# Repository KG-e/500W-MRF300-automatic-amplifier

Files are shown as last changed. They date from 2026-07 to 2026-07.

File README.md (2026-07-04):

# 500W-MRF300-automatic-amplifier

A fully automatic 500 W HF amateur radio amplifier (3.5–28 MHz) using a push-pull MRF300 LDMOS output stage with transmission-line transformers (TLTs). The amplifier automatically measures operating frequency, selects the appropriate low-pass filter, adjusts input drive power, monitors protection systems, and includes an automatic antenna tuner and touchscreen HMI.

**Author:** S56KG (https://www.qrz.com/db/S56KG)
This was a final-year high school project (slovenian "tehnična poklicna matura")

---

## Overview

Commercial automatic HF amplifiers with equivalent specs typically cost **3,000–5,000€**. This project was set out to build a comparable **500W HF amplifier** - with automatic band switching, automatic input leveling (attenuator), and full protection circuitry - for half the price (built for ~1,500€ including six output transistors lost to testing mishaps; a second build would cost roughly **1,300€**).

Unlike most homebrew amplifiers, the goal here was full automation: no manual band switching, no manual tuning sequence - just key up and go.

klub

## Key Features

- **Fully automatic operation** - no manual warm-up/tuning procedure required
- **Automatic input attenuator** with power measurement, stepping through 0.5–6 dB stages to hit an ideal ~4W drive level
- **Push-pull output stage** using 2× MRF300 LDMOS transistors, up to ~530W PEP, depending on freq.
- **Automatic low-pass filter selection** based on measured carrier frequency (LPF harmonics are ≤ −65 dBc)
- **Dual-MCU architecture** (2× ATmega2560) communicating over UART, with a custom protocol (type-checked, range-checked, heartbeat-monitored)
- **Nextion touchscreen HMI** showing forward/reflected power, SWR, current, temperature, state, band, gain, and losses in real time
- **Full protection**: overcurrent shutdown (soft-latched via SET-RESET logic), SWR protection, thermal protection, bias monitoring
- **Built-in antenna tuner board** (7x7 L-network, based on the N7DDC ATU-100 topology) - hardware complete, control algorithm in testing
- Extra feature connectors for future interfacing (not yet made PC digital control using a PiPico server) 
- Backup analog voltage/current meter on the front panel

## Design Goals

- At least 450W output
- Fully automatic operation without manual tuning
- Comprehensive protection for the MRF300 output devices 
- Support contest-style rapid TX/RX switching
- Maintain harmonic suppression below −65 dBc
- Operate from 3.5–28 MHz with automatic band detection
- Provide a commercial-style touchscreen HMI for all key operational values
- Build using only readily available components on DigiKey

## How It Works

block sheme

**Transmit state machine:** `INIT → WAIT → FIRST START → INPUT SETUP → LOW POWER TX → TX SWITCH → HIGH POWER TX → READY`. The "ready" state remembers the last transmission and skips most of the setup sequence on the next key-up for faster switching, useful for competition use.

statemachine

## Power/SWR Measurement

Power and SWR are measured using a **tandem match coupler**, rather than a simple directional coupler, since directional couplers perform poorly at low freq. HF. Two transformers (current and voltage) are summed/negated to separate forward and reflected power. Each direction feeds an **AD8310** logarithmic RF power detector (for accuracy across a wide dynamic range, from milliwatts to hundreds of watts), digitized by two 16-bit **ADS1115** ADCs over I2C.

## Boards 
| 1 | Attenuator board | Auto input attenuator (relay-switched, 0.5–6 dB stages, 8 stage), input power/SWR meter, built-in 50ohm dummy load 

| 2 | MCU board | Carrier board for ATmega2560 + ATmega16U2 (Arduino Mega-derived); one per controller 

| 3 | Amplifier board | Push-pull 2× MRF300 output stage, TLT output transformers, high-side current sensing, hardware overcurrent latch 

| 4 | Filter board | Output power/SWR metering + auto-selected low-pass filters (designed in AADE Filter Design + LTspice) 

| 5 | Tuner board | 7x7 L-network automatic antenna tuner (hardware complete, not yet enabled) 

| 6 | Motherboard | MCU carrier, per-board regulated supplies, fan control (6× PWM), 2× ADS1115 ADC, buzzer, overcurrent sensing 

| 7 | Input board | RX/TX switching (opto-isolated relay drive), 50V enable, frequency counter 

All boards are 4-layer FR4 (except the tuner board, 2-layer), designed with trace impedance calculated per JLCPCB dielectric specs.

## Firmware

- Two **ATmega2560** microcontrollers, split because driving the Nextion HMI alone slows a single loop to >30ms. This separates time-critical amplifier control from the touchscreen interface to guarantee deterministic protection response.
  - **Primary MCU**: runs the amplifier state machine, controls the amp stage, PSU, RF switching, attenuator, and filters; measures frequency and enforces fast protection (SWR, current, voltage) every loop.
  - **Secondary MCU**: reads temperature/voltage sensors, drives cooling fans, and manages the Nextion HMI.
- Custom UART protocol between the two MCUs with type checking, range validation, and a heartbeat/ID exchange so a reset on either side is detected.
- Faults are split into **soft** (recoverable, resettable from the HMI) and **hard** (critical) — the system is designed so no single fault destroys hardware (in theory, needs more testing to be sure).
- Developed in PlatformIO / VS Code (migrated from Arduino IDE to allow project specific library configuration, needed to change the UART RX buffer without touching global libraries).
- Combined firmware exceeds 3,000 lines across both MCUs.

## HMI

A **Nextion NX4832F035** touchscreen HMI displays input/output power and SWR (with slider gauges), current, temperature, operating state, faults, detected band, gain, and loss — with on-screen soft-fault reset and SSB mode toggle buttons.

## Power Supply

- Toroidal transformer 1200VA and 17V iron core feeding regulated **50V** and **18V** rails respectively, plus soft-start circuitry (needed after an initial testing inrush blew ten smd fuses at once).
- 50V rail: 5x TIP35C NPN transistors (more than strictly needed by current, added for thermal headroom due to insulators).
- 18V rail: 5x LM7818 in a balanced parallel configuration.
- Each PCB has its own local LM78xx/LT1117 regulation on the motherboard to isolate RF noise between stages — important since the amplifier operates on the same frequencies the MCUs use internally.
- Tested at 800W (80% load) for several hours for thermal verification.

## Specifications

| Parameter | Value |
|---|---|
| Output power | 450–500 W (typ.) |
| Accepted drive power | 7–110 W |
| Bands | 3.5, 7, 10, 14, 18, 21, 27 (CB), 28 MHz |
| Gain | > 17 dB (typ.) |
| DC-RF efficiency | ~50% |
| Modes | FM, SSB |
| Harmonics | ≤ −65 dBc |
| Max. antenna SWR | 4:1 |
| Weight | 21.3 kg |
| Dimensions (DxWxH) | 48 × 44 × 20 cm |

## Known Issues

- Occasional spurious fault triggering under unusual operating conditions
- Secondary MCU can fail to start correctly, due to a Nextion library issue that stalls its main loop
- AM modulation is not supported (breaks the frequency counter)
- Reduced output power on the 28 MHz band, due to a suboptimal low-pass filter design in the current revision
- Higher drive power required on 21 MHz and 28 MHz (12W, compared to 7W on 3.5MHz) due to RF detector attenuation characteristics
- The bad 28 MHz LPF has elevated output SWR, degrading output power/SWR readings on that band
- Automatic antenna tuner's hardware is complete but not yet fully tested as the matching algorithm is a difficult mechanism, still under development 
- Lower than desired efficiency of the amp stage, currently about 50%, which pushes power dissipation to the limit
 
This project is shared as inspiration for design ideas, for other homebrew amp builders. I do not recommend attempting to recreate my exact design as there are many subtle details one must account for when building it that you may not know or find unless you are very thorough and understanding of the design.

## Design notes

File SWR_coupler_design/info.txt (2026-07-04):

The design of the coupler was copied from https://vk6nx.net/SWR-PWRmeter_v1.0-en.html#00
Only small changes were made from this example.

The coupler is accurate to +-0.2W when Pin<10W, +-1W when Pin>100W. Directivity is around 20dB with the internal shielding in the toroid (look at input bridge picture) 
and around 15dB without (look at output bridge picture). Directivity worsens with higher input power. This is due to the stray capacitance between the fwd and rev ports.

This design can handle around 1kW of power. vk6nex lists 2kW, but calculating directivity drop makes it unusable as a actual SWR meter at those powers.

Added file is a example cal table from the amplifier. To get cal values i actualy reccomend putting the data into a LLM such as Claude, to speed up brute 
calibration factor calculations... Cal values are stored in the custom ADC library.

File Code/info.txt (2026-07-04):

If you wish correctly open these files, you must download Visual Studio Code and the platformio extension for the files to combine correctly.

Libraries ADC and UART are custom made for this project, it is not reccomended to use them out of this scope unless you realy know what you are doing.

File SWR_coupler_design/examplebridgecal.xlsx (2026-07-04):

OUTPUT BRIDGE | TrueFwdW | 29MEG | FWD | REW | TrueFwdW | 24MEG | FWD | REW | TrueFwdW | 14MEG | FWD | REW | TrueFwdW | 7MEG | FWD | REW | TrueFwdW | 3.5MEG | FWD | REW
 | 9 |  | 2037 | 1789 | 9.5 |  | 2043 | 1772 | 9.5 |  | 2043 | 1671 | 10 |  | 2045 | 1542 | 10 |  | 2049 | 1425
 | 19 |  | 2110 | 1859 | 19 |  | 2117 | 1884 | 20 |  | 2121 | 1745 | 20 |  | 2122 | 1610 | 20 |  | 2127 | 1500
 | 38 |  | 2186 | 1929 | 40 |  | 2193 | 1916 | 40 |  | 2196 | 1820 | 40 |  | 2196 | 1677 | 40 |  | 2201 | 1569
 | 57 |  | 2227 | 1968 | 60 |  | 2236 | 1955 | 60 |  | 2238 | 1835 | 60 |  | 2239 | 1721 | 60 |  | 2245 | 1609
 | 75 |  | 2257 | 1997 | 80 |  | 2265 | 1985 | 81 |  | 2268 | 1868 | 80 |  | 2270 | 1754 | 81 |  | 2276 | 1639
 | 76 |  | 2260 | 2000 | 104 |  | 2291 | 2008 | 104 |  | 2290 | 1915 | 105 |  | 2295 | 1781 | 105 |  | 2302 | 1664
INPUT BRIDGE | TrueFwdW | 29MEG | FWD | REW | TrueFwdW | 24MEG | FWD | REW | TrueFwdW | 14MEG | FWD | REW | TrueFwdW | 7MEG | FWD | REW | TrueFwdW | 3.5MEG | FWD | REW
 | 10 |  | 2063 | 1700 | 10 |  | 2062 | 1652 | 10 |  | 2061 | 1496 | 10 |  | 2062 | 1371 | 10 |  | 2070 | 1351
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

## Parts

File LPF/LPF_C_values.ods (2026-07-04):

values for | F1 – 3.5 | F2 – 7 | F3 – 14 | F4 – 21 | F5 – 28 | C-pcb removed(17pF) | F1 – 3.5 | F2 – 7 | F3 – 14 | F4 – 21 | F5 – 28
C1 | 1100 | 545 | 280 | 165 | 125 | ---→ | 1083 | 528 | 263 | 148 | 108
C2 | 25 | 30 | 10 | 15 | 10 |  | 8 | 13 | -7 | -2 | -7
C3 | 1700 | 845 | 435 | 265 | 210 |  | 1683 | 828 | 418 | 248 | 193
C4 | 60 | 75 | 30 | 35 | 15 |  | 43 | 58 | 13 | 18 | -2
C5 | 900 | 505 | 260 | 145 | 120 |  | 883 | 488 | 243 | 128 | 103
L1 | 2.5 | 1.35 | 0.68 | 0.45 | 0.33
L2 | 2.55 | 1.25 | 0.63 | 0.38 | 0.32
 | F1 – 3.5 | <-stacked C | F2 – 7 | ←stacked C | F3 – 14 | ←stacked C | F4 – 21 | <-stacked C | F5 – 28 | ←stacked C |  | stacked C is due to the series connection of
 | 1083 | 2166 | 528 | 1056 | 263 | 526 | 148 | 296 | 108 | 216 |  | two capacitors for higher power and dissipation.
 | 8 | 16 | 13 | 26 | -7 | -14 | -2 | -4 | -7 | -14 |  | Use only large size capacitors, 1kV of C0G. Tune all LPF’s manually with a VNA connected.
 | 1683 | 3366 | 828 | 1656 | 418 | 836 | 248 | 496 | 193 | 386 |  | I advise the use of variable capacitors across all capacitor locations
 | 43 | 86 | 58 | 116 | 13 | 26 | 18 | 36 | -2 | -4 |  | to quickly estimate values for a correct response.
 | 883 | 1766 | 488 | 976 | 243 | 486 | 128 | 256 | 103 | 206 |  | Final check is via radio, 100W, checking input and output SWR
 |  |  |  |  |  |  |  |  |  |  |  | these are aproximate values. In my testing true values ranged in +-10%…
 |  | 2166 / 16 3366 / 86 1766 / |  | 1056 / 26 1656 / 116 976 / |  | 526 / -14 836 26 486 / |  | 296 -4 496 / 36 256 / |  | 216 / -14 386 -4 206 /
aprox |  | Capacitors to buy
2000 x2 + 100 x2 + 30 x4 |  | 2000 x4
3300 x2 + 30 x4 |  | 100 x30
1600 x4 + 100 x2 + 30 x4 |  | 30x30
900 x4 + 80 x2 + 30x4 |  | 80x10
480 x4 + 10 x4 |  | 10x30
800 x2 + 20 x8 |  | 3300 x4
200 x 12 + 20 x2 + 50 x2 |  | 20x 30
100 x4 + 50 x2 + 30 x2 |  | 50x 20
5p, 10p |  | 5x 30
 |  | 480 x14
 |  | 900 x6
 |  | 1600 x6

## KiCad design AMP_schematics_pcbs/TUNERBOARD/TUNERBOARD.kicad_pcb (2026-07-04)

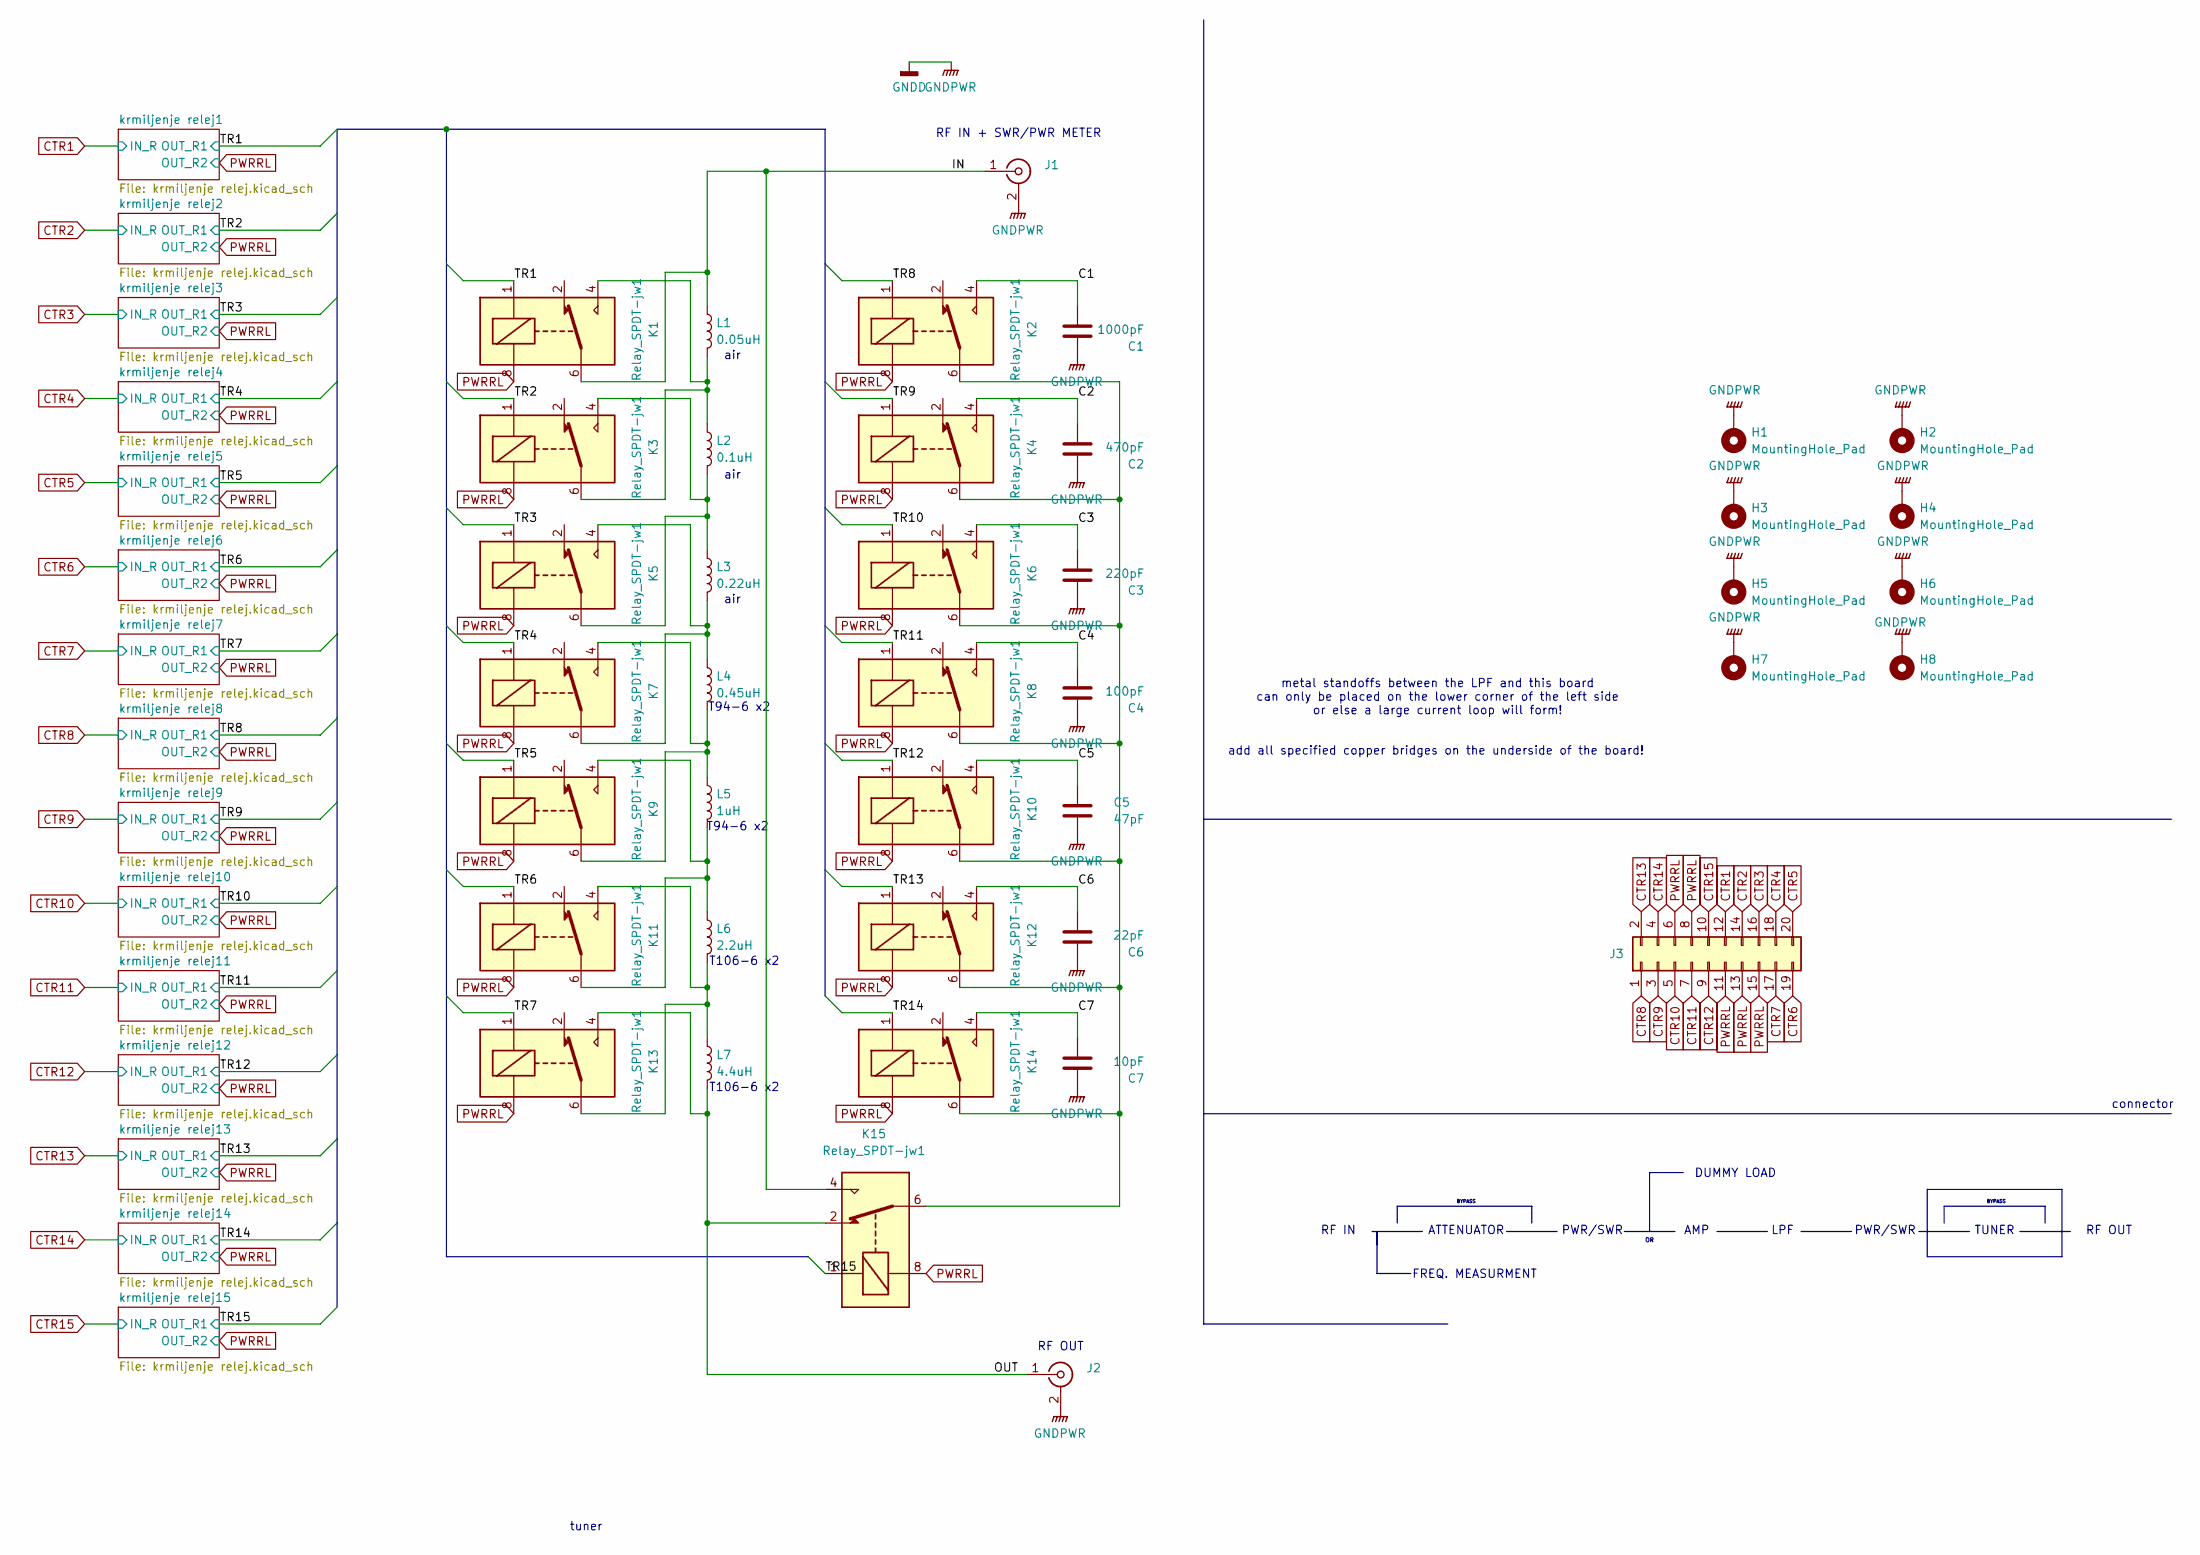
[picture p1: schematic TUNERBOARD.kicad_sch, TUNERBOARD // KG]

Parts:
C1: 1000pF; C_1210_3225Metric
C2: 470pF; C_1210_3225Metric
C3: 220pF; C_1210_3225Metric
C4: 100pF; C_1210_3225Metric
C5: 47pF; C_1210_3225Metric
C6: 22pF; C_1210_3225Metric
C7: 10pF; C_1210_3225Metric
H1, H2, H3, H4, H5, H6, H7, H8: MountingHole_Pad; MountingHole_3.2mm_M3_Pad_TopBottom
J1, J2: Conn_Coaxial; SMA_Amphenol_132134_Vertical
J3: Conn_02x10_Odd_Even; PinHeader_2x10_P2.54mm_Vertical
K1, K2, K3, K4, K5, K6, K7, K8, K9, K10, K11, K12, K13, K14, K15: Relay_SPDT-jw1; Relay_premaknjen
L1: 0.05uH; zracnatuljava
L2: 0.1uH; zracnatuljava
L3: 0.22uH; zracnatuljava
L4: 0.45uH; T94-postrani
L5: 1uH; T94-postrani
L6: 2.2uH; T106-lezec
L7: 4.4uH; T106-lezec

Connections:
/C1: C1.2, K2.4
/C2: C2.2, K4.4
/C3: C3.2, K6.4
/C4: C4.2, K8.4
/C5: C5.2, K10.4
/C6: C6.2, K12.4
/C7: C7.2, K14.4
/IN: J1.1 (In), K1.6, K15.4, L1.1
/OUT: J2.1 (In), K13.4, K15.2, L7.2
/TR1: K1.1; also elsewhere on the board
/TR2: K3.1; also elsewhere on the board
/TR3: K5.1; also elsewhere on the board
/TR4: K7.1; also elsewhere on the board
/TR5: K9.1; also elsewhere on the board
/TR6: K11.1; also elsewhere on the board
/TR7: K13.1; also elsewhere on the board
/TR8: K2.1; also elsewhere on the board
/TR9: K4.1; also elsewhere on the board
/TR10: K6.1; also elsewhere on the board
/TR11: K8.1; also elsewhere on the board
/TR12: K10.1; also elsewhere on the board
/TR13: K12.1; also elsewhere on the board
/TR14: K14.1; also elsewhere on the board
/TR15: K15.1; also elsewhere on the board
CTR1: J3.12; also elsewhere on the board
CTR2: J3.14; also elsewhere on the board
CTR3: J3.16; also elsewhere on the board
CTR4: J3.18; also elsewhere on the board
CTR5: J3.20; also elsewhere on the board
CTR6: J3.19; also elsewhere on the board
CTR7: J3.17; also elsewhere on the board
CTR8: J3.1; also elsewhere on the board
CTR9: J3.3; also elsewhere on the board
CTR10: J3.5; also elsewhere on the board
CTR11: J3.7; also elsewhere on the board
CTR12: J3.9; also elsewhere on the board
CTR13: J3.2; also elsewhere on the board
CTR14: J3.4; also elsewhere on the board
CTR15: J3.10; also elsewhere on the board
GNDD: C1.1, C2.1, C3.1, C4.1, C5.1, C6.1, C7.1, H1.1, H2.1, H3.1, H4.1, H5.1, H6.1, H7.1, H8.1, J1.2 (Ext), J2.2 (Ext); also elsewhere on the board
unnamed: K1.4, K3.6, L1.2, L2.1
unnamed: K3.4, K5.6, L2.2, L3.1
unnamed: K5.4, K7.6, L3.2, L4.1
unnamed: K7.4, K9.6, L4.2, L5.1
unnamed: K2.6, K4.6, K6.6, K8.6, K10.6, K12.6, K14.6, K15.6
unnamed: K11.4, K13.6, L6.2, L7.1
unnamed: K9.4, K11.6, L5.2, L6.1
PWRRL: J3.6, J3.8, J3.11, J3.13, J3.15, K1.8, K2.8, K3.8, K4.8, K5.8, K6.8, K7.8, K8.8, K9.8, K10.8, K11.8, K12.8, K13.8, K14.8, K15.8; also elsewhere on the board

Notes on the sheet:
T106-6 x2
ATTENUATOR
add all specified copper bridges on the underside of the board!
DUMMY LOAD
RF OUT
FREQ. MEASURMENT
AMP
LPF
air
PWR/SWR
RF OUT
RF IN + SWR/PWR METER
BYPASS
T94-6 x2
TUNER
RF IN
tuner
metal standoffs between the LPF and this board can only be placed on the lower corner of the left side or else a large current loop will form!
connector

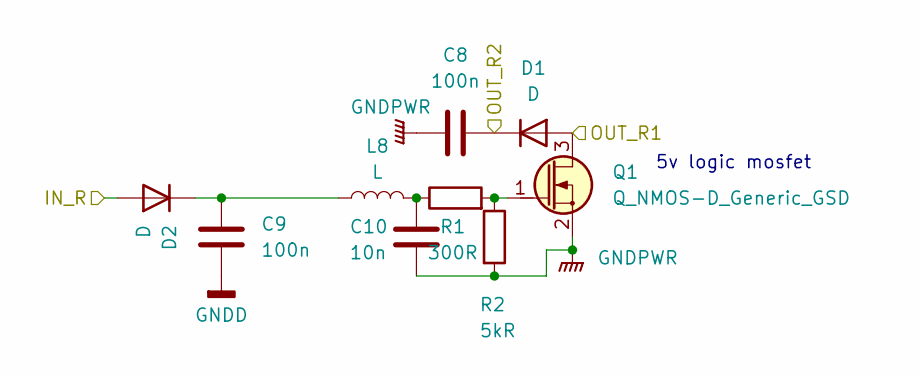
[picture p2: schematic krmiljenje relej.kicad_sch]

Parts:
C8, C9: 100n; C_1206_3216Metric_Pad1.33x1.80mm_HandSolder
C10: 10n; C_1206_3216Metric_Pad1.33x1.80mm_HandSolder
D1, D2: D; D_1206_3216Metric_Pad1.42x1.75mm_HandSolder
L8: L; Ferrite_1206_3216Metric_Pad1.42x1.75mm_BigPads
Q1: Q_NMOS-D_Generic_GSD; TSOT-23_HandSoldering
R1: 300R; R_1206_3216Metric_Pad1.30x1.75mm_HandSolder
R2: 5kR; R_1206_3216Metric_Pad1.30x1.75mm_HandSolder

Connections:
/TR1: D1.2 (A), Q1.3 (D); also elsewhere on the board
CTR1: D2.2 (A); also elsewhere on the board
GNDD: C8.2, C9.2, C10.2, Q1.2 (S), R2.2; also elsewhere on the board
unnamed: C10.1, L8.2, R1.1
unnamed: C9.1, D2.1 (K), L8.1
unnamed: Q1.1 (G), R1.2, R2.1
PWRRL: C8.1, D1.1 (K); also elsewhere on the board

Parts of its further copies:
C11, C12, C14, C15, C17, C18, C20, C21, C23, C24, C26, C27, C29, C30, C32, C33, C35, C36, C38, C39, C41, C42, C44, C45, C47, C48, C50, C51: 100n; C_1206_3216Metric_Pad1.33x1.80mm_HandSolder
C13, C16, C19, C22, C25, C28, C31, C34, C37, C40, C43, C46, C49, C52: 10n; C_1206_3216Metric_Pad1.33x1.80mm_HandSolder
D3, D4, D5, D6, D7, D8, D9, D10, D11, D12, D13, D14, D15, D16, D17, D18, D19, D20, D21, D22, D23, D24, D25, D26, D27, D28, D29, D30: D; D_1206_3216Metric_Pad1.42x1.75mm_HandSolder
L9, L10, L11, L12, L13, L14, L15, L16, L17, L18, L19, L20, L21, L22: L; Ferrite_1206_3216Metric_Pad1.42x1.75mm_BigPads
Q2, Q3, Q4, Q5, Q6, Q7, Q8, Q9, Q10, Q11, Q12, Q13, Q14, Q15: Q_NMOS-D_Generic_GSD; TSOT-23_HandSoldering
R3, R5, R7, R9, R11, R13, R15, R17, R19, R21, R23, R25, R27, R29: 300R; R_1206_3216Metric_Pad1.30x1.75mm_HandSolder
R4, R6, R8, R10, R12, R14, R16, R18, R20, R22, R24, R26, R28, R30: 5kR; R_1206_3216Metric_Pad1.30x1.75mm_HandSolder

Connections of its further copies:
/TR2: D3.2 (A), Q2.3 (D); also elsewhere on the board
/TR3: D5.2 (A), Q3.3 (D); also elsewhere on the board
/TR4: D7.2 (A), Q4.3 (D); also elsewhere on the board
/TR5: D9.2 (A), Q5.3 (D); also elsewhere on the board
/TR6: D11.2 (A), Q6.3 (D); also elsewhere on the board
/TR7: D13.2 (A), Q7.3 (D); also elsewhere on the board
/TR8: D15.2 (A), Q8.3 (D); also elsewhere on the board
/TR9: D17.2 (A), Q9.3 (D); also elsewhere on the board
/TR10: D19.2 (A), Q10.3 (D); also elsewhere on the board
/TR11: D21.2 (A), Q11.3 (D); also elsewhere on the board
/TR12: D23.2 (A), Q12.3 (D); also elsewhere on the board
/TR13: D25.2 (A), Q13.3 (D); also elsewhere on the board
/TR14: D27.2 (A), Q14.3 (D); also elsewhere on the board
/TR15: D29.2 (A), Q15.3 (D); also elsewhere on the board
CTR2: D4.2 (A); also elsewhere on the board
CTR3: D6.2 (A); also elsewhere on the board
CTR4: D8.2 (A); also elsewhere on the board
CTR5: D10.2 (A); also elsewhere on the board
CTR6: D12.2 (A); also elsewhere on the board
CTR7: D14.2 (A); also elsewhere on the board
CTR8: D16.2 (A); also elsewhere on the board
CTR9: D18.2 (A); also elsewhere on the board
CTR10: D20.2 (A); also elsewhere on the board
CTR11: D22.2 (A); also elsewhere on the board
CTR12: D24.2 (A); also elsewhere on the board
CTR13: D26.2 (A); also elsewhere on the board
CTR14: D28.2 (A); also elsewhere on the board
CTR15: D30.2 (A); also elsewhere on the board
GNDD: C11.2, C12.2, C13.2, C14.2, C15.2, C16.2, C17.2, C18.2, C19.2, C20.2, C21.2, C22.2, C23.2, C24.2, C25.2, C26.2, C27.2, C28.2, C29.2, C30.2, C31.2, C32.2, C33.2, C34.2, C35.2, C36.2, C37.2, C38.2, C39.2, C40.2, C41.2, C42.2, C43.2, C44.2, C45.2, C46.2, C47.2, C48.2, C49.2, C50.2, C51.2, C52.2, Q2.2 (S), Q3.2 (S), Q4.2 (S), Q5.2 (S), Q6.2 (S), Q7.2 (S), Q8.2 (S), Q9.2 (S), Q10.2 (S), Q11.2 (S), Q12.2 (S), Q13.2 (S), Q14.2 (S), Q15.2 (S), R4.2, R6.2, R8.2, R10.2, R12.2, R14.2, R16.2, R18.2, R20.2, R22.2, R24.2, R26.2, R28.2, R30.2; also elsewhere on the board
unnamed: C13.1, L9.2, R3.1
unnamed: C16.1, L10.2, R5.1
unnamed: C19.1, L11.2, R7.1
unnamed: C22.1, L12.2, R9.1
unnamed: C25.1, L13.2, R11.1
unnamed: C28.1, L14.2, R13.1
unnamed: C31.1, L15.2, R15.1
unnamed: C34.1, L16.2, R17.1
unnamed: C37.1, L17.2, R19.1
unnamed: C40.1, L18.2, R21.1
unnamed: C43.1, L19.2, R23.1
unnamed: C46.1, L20.2, R25.1
unnamed: C49.1, L21.2, R27.1
unnamed: C52.1, L22.2, R29.1
unnamed: C12.1, D4.1 (K), L9.1
unnamed: C15.1, D6.1 (K), L10.1
unnamed: C18.1, D8.1 (K), L11.1
unnamed: C21.1, D10.1 (K), L12.1
unnamed: C24.1, D12.1 (K), L13.1
unnamed: C27.1, D14.1 (K), L14.1
unnamed: C30.1, D16.1 (K), L15.1
unnamed: C33.1, D18.1 (K), L16.1
unnamed: C36.1, D20.1 (K), L17.1
unnamed: C39.1, D22.1 (K), L18.1
unnamed: C42.1, D24.1 (K), L19.1
unnamed: C45.1, D26.1 (K), L20.1
unnamed: C48.1, D28.1 (K), L21.1
unnamed: C51.1, D30.1 (K), L22.1
unnamed: Q2.1 (G), R3.2, R4.1
unnamed: Q3.1 (G), R5.2, R6.1
unnamed: Q4.1 (G), R7.2, R8.1
unnamed: Q5.1 (G), R9.2, R10.1
unnamed: Q6.1 (G), R11.2, R12.1
unnamed: Q7.1 (G), R13.2, R14.1
unnamed: Q8.1 (G), R15.2, R16.1
unnamed: Q9.1 (G), R17.2, R18.1
unnamed: Q10.1 (G), R19.2, R20.1
unnamed: Q11.1 (G), R21.2, R22.1
unnamed: Q12.1 (G), R23.2, R24.1
unnamed: Q13.1 (G), R25.2, R26.1
unnamed: Q14.1 (G), R27.2, R28.1
unnamed: Q15.1 (G), R29.2, R30.1
PWRRL: C11.1, C14.1, C17.1, C20.1, C23.1, C26.1, C29.1, C32.1, C35.1, C38.1, C41.1, C44.1, C47.1, C50.1, D3.1 (K), D5.1 (K), D7.1 (K), D9.1 (K), D11.1 (K), D13.1 (K), D15.1 (K), D17.1 (K), D19.1 (K), D21.1 (K), D23.1 (K), D25.1 (K), D27.1 (K), D29.1 (K); also elsewhere on the board

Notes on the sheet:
5v logic mosfet

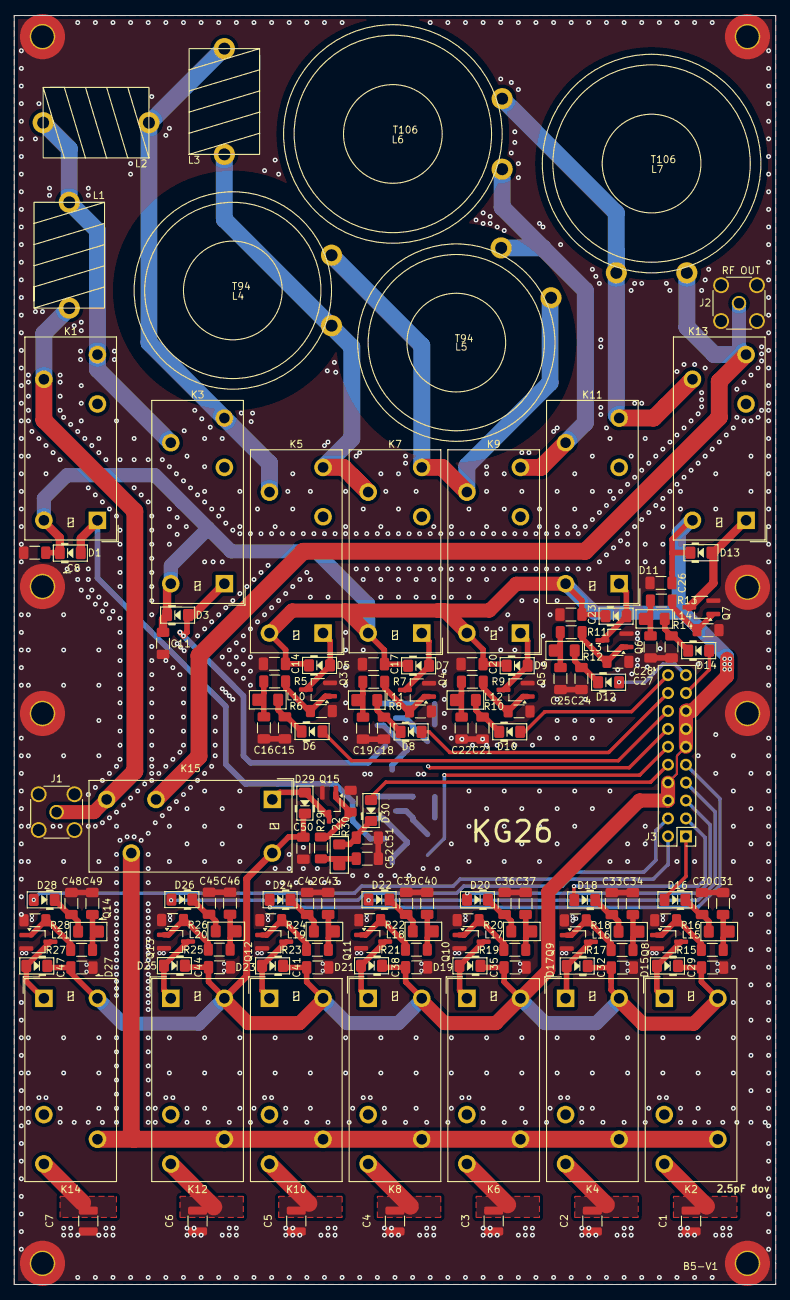
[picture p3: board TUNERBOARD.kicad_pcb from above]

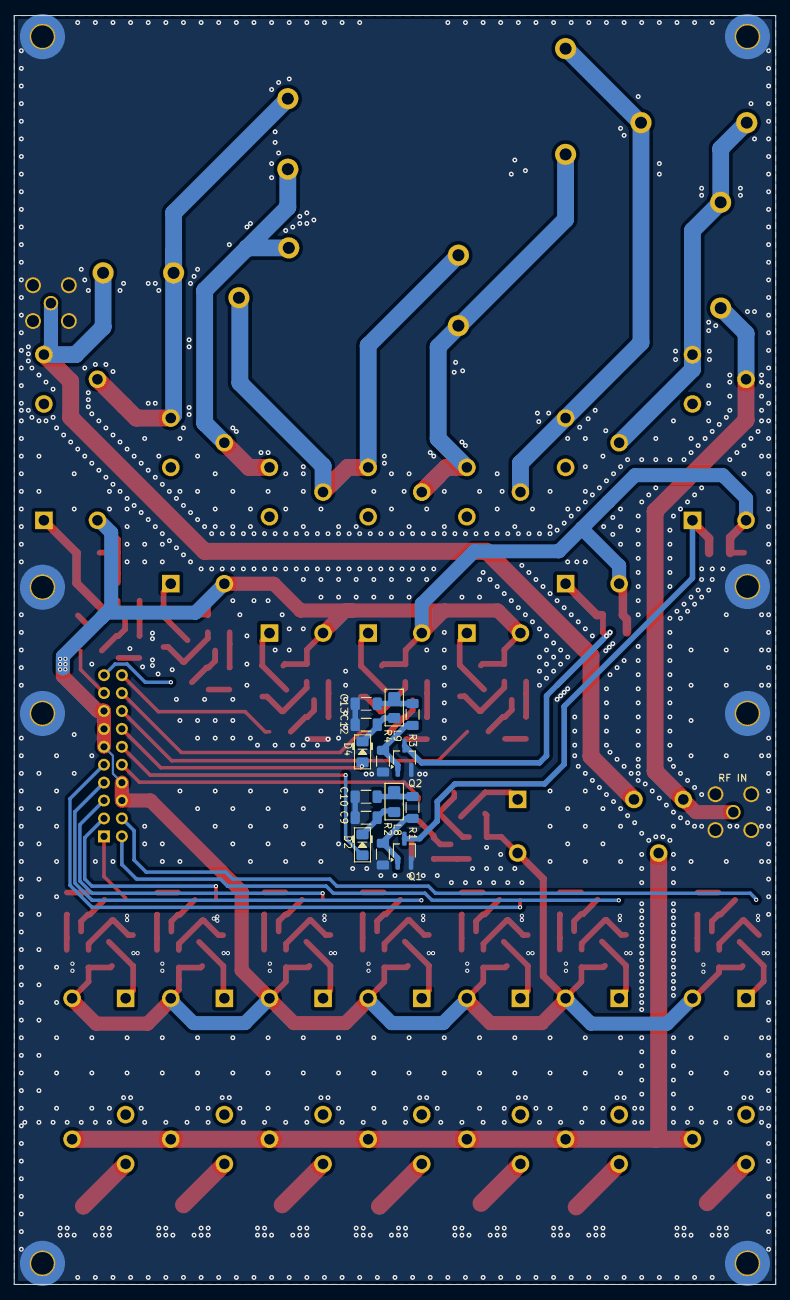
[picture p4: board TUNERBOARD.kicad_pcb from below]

Board: 2 copper layers, 108.0 x 180.0 mm, 175 parts (14 on the bottom side), 93 nets.

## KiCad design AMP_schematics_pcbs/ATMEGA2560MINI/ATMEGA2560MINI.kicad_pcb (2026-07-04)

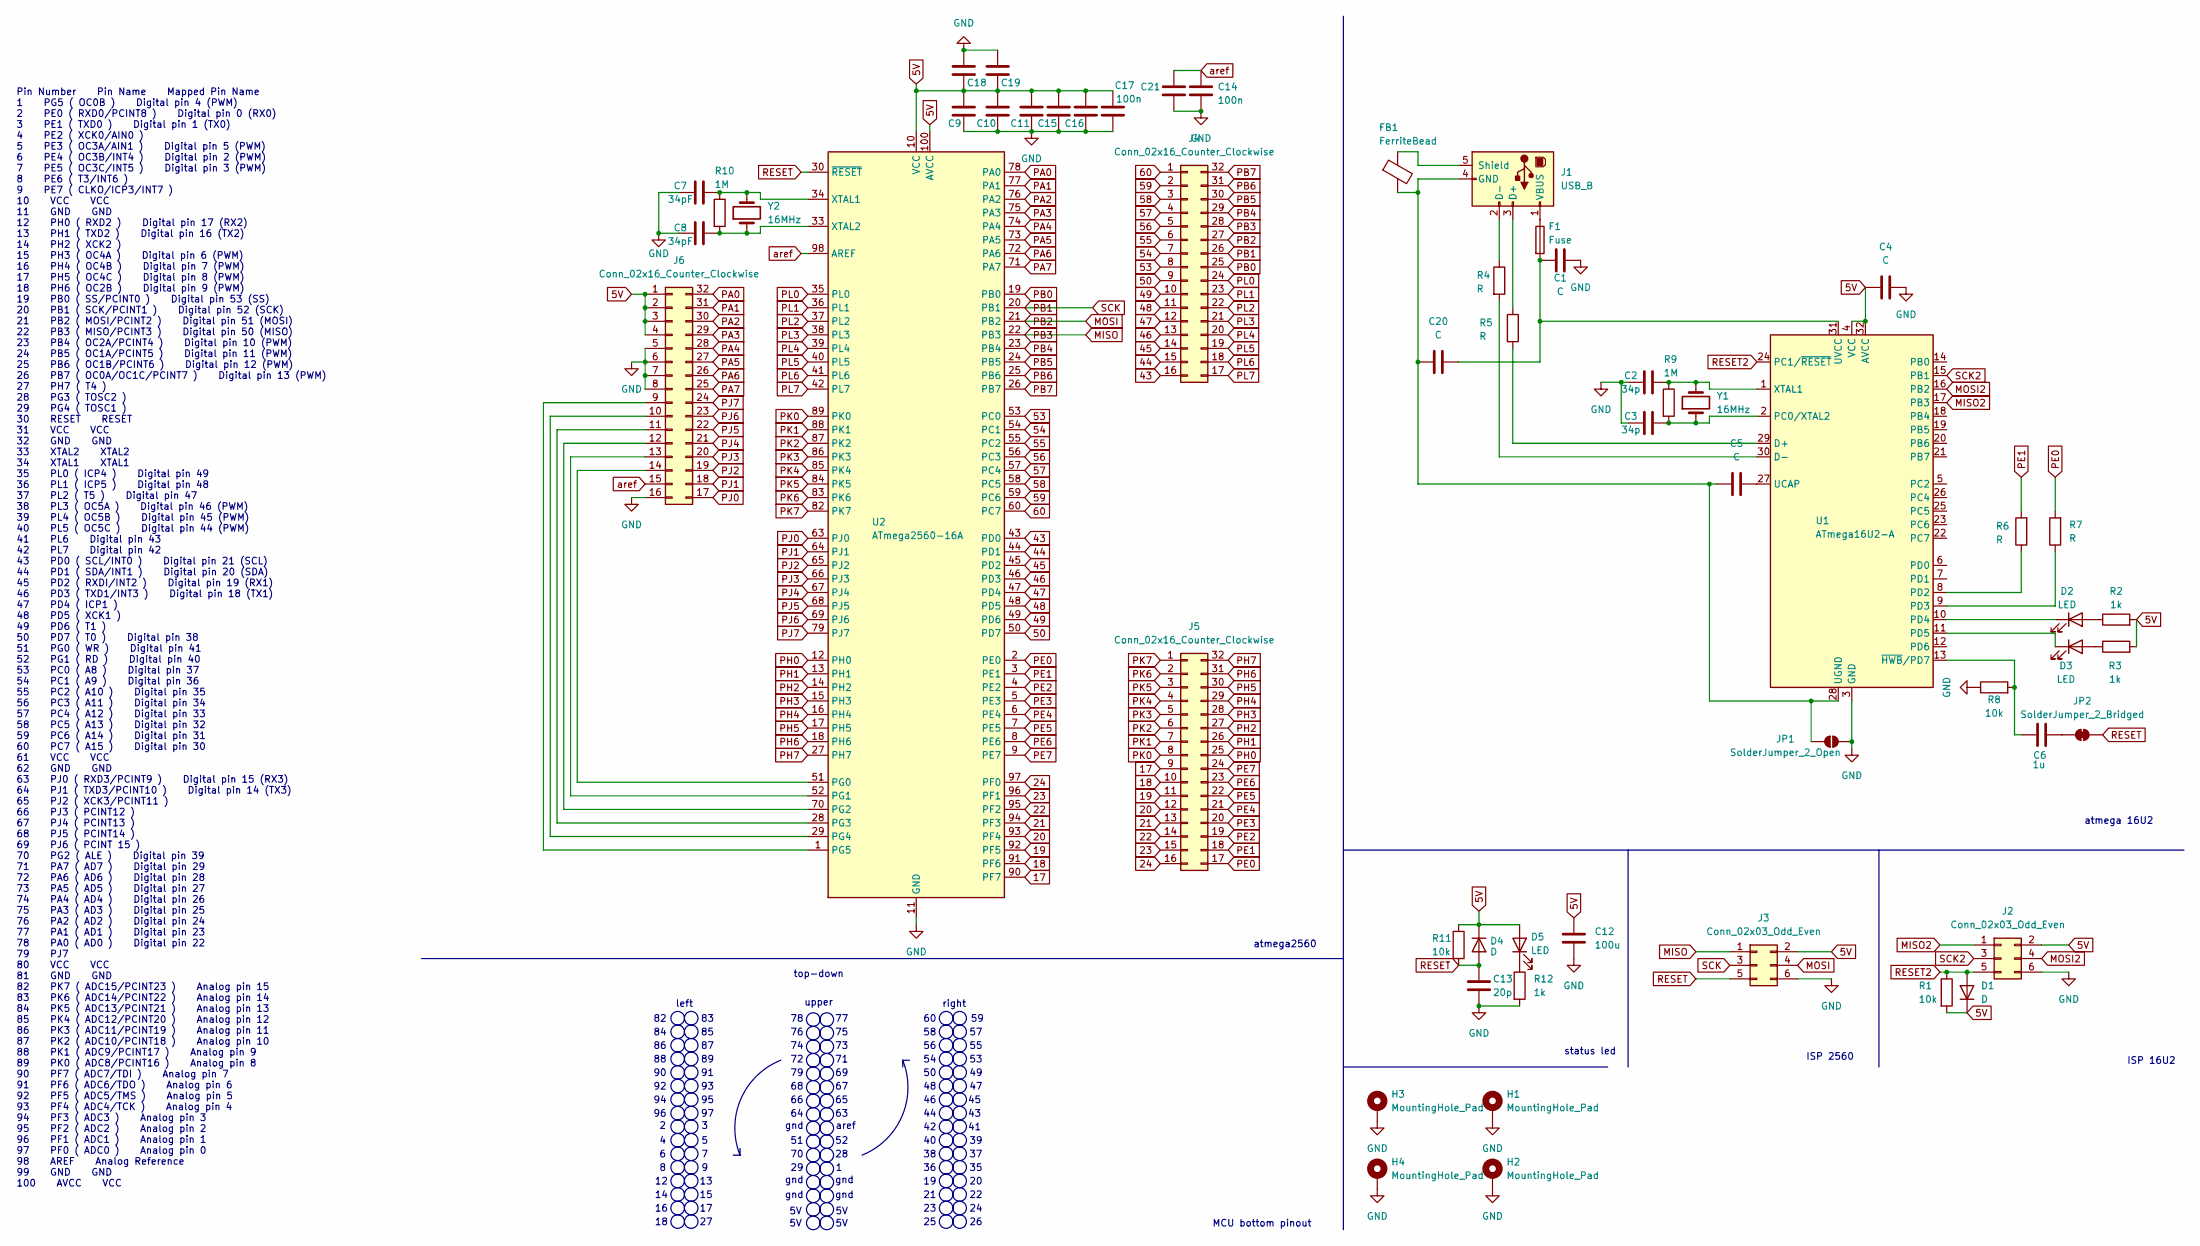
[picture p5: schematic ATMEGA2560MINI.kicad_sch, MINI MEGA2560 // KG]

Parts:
C1, C4, C5, C9, C10, C11, C15, C16, C18, C19, C20, C21: C; C_1206_3216Metric_Pad1.33x1.80mm_HandSolder
C2, C3: 34p; C_1206_3216Metric_Pad1.33x1.80mm_HandSolder
C6: 1u; C_1206_3216Metric_Pad1.33x1.80mm_HandSolder
C7, C8: 34pF; C_1206_3216Metric_Pad1.33x1.80mm_HandSolder
C12: 100u; CP_Elec_8x10
C13: 20p; C_1206_3216Metric_Pad1.33x1.80mm_HandSolder
C14, C17: 100n; C_1206_3216Metric_Pad1.33x1.80mm_HandSolder
D1, D4: D; D_1206_3216Metric_Pad1.42x1.75mm_HandSolder
D2, D3, D5: LED; LED_0805_2012Metric_Pad1.15x1.40mm_HandSolder
F1: Fuse; Fuse_1206_3216Metric_Pad1.42x1.75mm_HandSolder
FB1: FerriteBead; L_1806_4516Metric_Pad1.45x1.90mm_HandSolder
H1, H2, H3, H4: MountingHole_Pad; MountingHole_3.2mm_M3_ISO14580_Pad_TopBottom
J1: USB_B; USB_B_TE_5787834_Vertical
J2, J3: Conn_02x03_Odd_Even; PinSocket_2x03_P2.54mm_Vertical
J4, J5, J6: Conn_02x16_Counter_Clockwise; PinHeader_2x16_P2.54mm_Vertical
JP1: SolderJumper_2_Open; SolderJumper-2_P1.3mm_Open_RoundedPad1.0x1.5mm
JP2: SolderJumper_2_Bridged; SolderJumper-2_P1.3mm_Bridged2Bar_RoundedPad1.0x1.5mm
R1, R8, R11: 10k; R_1206_3216Metric_Pad1.30x1.75mm_HandSolder
R2, R3, R12: 1k; R_1206_3216Metric_Pad1.30x1.75mm_HandSolder
R4, R5, R6, R7: R; R_1206_3216Metric_Pad1.30x1.75mm_HandSolder
R9, R10: 1M; R_1206_3216Metric_Pad1.30x1.75mm_HandSolder
U1: ATmega16U2-A; TQFP-32_7x7mm_P0.8mm
U2: ATmega2560-16A; TQFP-100_14x14mm_P0.5mm
Y1, Y2: 16MHz; Crystal_HC49-U_Vertical

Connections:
5V: C4.1, C9.2, C10.2, C11.2, C12.1, C15.2, C16.2, C17.2, C18.2, C19.2, D1.1 (K), D4.1 (K), D5.2 (A), J2.2, J3.2, J6.1, J6.2, J6.3, J6.4, R1.2, R2.2, R3.2, R11.1, U1.4 (VCC), U1.32 (AVCC), U2.10 (VCC), U2.31 (VCC), U2.61 (VCC), U2.80 (VCC), U2.100 (AVCC)
17: J5.9, U2.90 (PF7)
18: J5.10, U2.91 (PF6)
19: J5.11, U2.92 (PF5)
20: J5.12, U2.93 (PF4)
21: J5.13, U2.94 (PF3)
22: J5.14, U2.95 (PF2)
23: J5.15, U2.96 (PF1)
24: J5.16, U2.97 (PF0)
43: J4.16, U2.43 (PD0)
44: J4.15, U2.44 (PD1)
45: J4.14, U2.45 (PD2)
46: J4.13, U2.46 (PD3)
47: J4.12, U2.47 (PD4)
48: J4.11, U2.48 (PD5)
49: J4.10, U2.49 (PD6)
50: J4.9, U2.50 (PD7)
53: J4.8, U2.53 (PC0)
54: J4.7, U2.54 (PC1)
55: J4.6, U2.55 (PC2)
56: J4.5, U2.56 (PC3)
57: J4.4, U2.57 (PC4)
58: J4.3, U2.58 (PC5)
59: J4.2, U2.59 (PC6)
60: J4.1, U2.60 (PC7)
GND: C1.2, C2.1, C3.1, C4.2, C7.1, C8.1, C9.1, C10.1, C11.1, C12.2, C13.2, C14.1, C15.1, C16.1, C17.1, C18.1, C19.1, C21.1, H1.1, H2.1, H3.1, H4.1, J2.6, J3.6, J6.5, J6.6, J6.7, J6.8, J6.16, JP1.2 (B), R8.1, R12.2, U1.3 (GND), U2.11 (GND), U2.32 (GND), U2.62 (GND), U2.81 (GND), U2.99 (GND)
MISO: J3.1, J4.28, U2.22 (PB3)
MISO2: J2.1, U1.17 (PB3)
MOSI: J3.4, J4.27, U2.21 (PB2)
MOSI2: J2.4, U1.16 (PB2)
unnamed: D2.2 (A), R2.1
unnamed: D2.1 (K), U1.10 (PD4)
unnamed: D3.2 (A), R3.1
unnamed: D3.1 (K), U1.11 (PD5)
unnamed: D5.1 (K), R12.1
unnamed: J1.3 (D+), R5.1
unnamed: J1.2 (D-), R4.1
unnamed: C5.1, C20.2, FB1.2, J1.4 (GND), JP1.1 (A), U1.28 (UGND)
unnamed: FB1.1, J1.5 (Shield)
unnamed: F1.1, J1.1 (VBUS)
unnamed: J6.9, U2.1 (PG5)
unnamed: J6.10, U2.29 (PG4)
unnamed: J6.11, U2.28 (PG3)
unnamed: J6.12, U2.70 (PG2)
unnamed: J6.13, U2.52 (PG1)
unnamed: J6.14, U2.51 (PG0)
unnamed: C6.2, JP2.1 (A)
unnamed: R5.2, U1.29 (D+)
unnamed: R4.2, U1.30 (D-)
unnamed: C3.2, R9.2, U1.2 (PC0/XTAL2), Y1.1
unnamed: R6.1, U1.8 (PD2)
unnamed: R7.1, U1.9 (PD3)
unnamed: C5.2, U1.27 (UCAP)
unnamed: C1.1, C20.1, F1.2, U1.31 (UVCC)
unnamed: C2.2, R9.1, U1.1 (XTAL1), Y1.2
unnamed: C6.1, R8.2, U1.13 (~HWB/PD7)
unnamed: C7.2, R10.1, U2.34 (XTAL1), Y2.2
unnamed: C8.2, R10.2, U2.33 (XTAL2), Y2.1
PA0: J6.32, U2.78 (PA0)
PA1: J6.31, U2.77 (PA1)
PA2: J6.30, U2.76 (PA2)
PA3: J6.29, U2.75 (PA3)
PA4: J6.28, U2.74 (PA4)
PA5: J6.27, U2.73 (PA5)
PA6: J6.26, U2.72 (PA6)
PA7: J6.25, U2.71 (PA7)
PB0: J4.25, U2.19 (PB0)
PB1: J3.3, J4.26, U2.20 (PB1)
PB4: J4.29, U2.23 (PB4)
PB5: J4.30, U2.24 (PB5)
PB6: J4.31, U2.25 (PB6)
PB7: J4.32, U2.26 (PB7)
PE0: J5.17, R7.2, U2.2 (PE0)
PE1: J5.18, R6.2, U2.3 (PE1)
PE2: J5.19, U2.4 (PE2)
PE3: J5.20, U2.5 (PE3)
PE4: J5.21, U2.6 (PE4)
PE5: J5.22, U2.7 (PE5)
PE6: J5.23, U2.8 (PE6)
PE7: J5.24, U2.9 (PE7)
PH0: J5.25, U2.12 (PH0)
PH1: J5.26, U2.13 (PH1)
PH2: J5.27, U2.14 (PH2)
PH3: J5.28, U2.15 (PH3)
PH4: J5.29, U2.16 (PH4)
PH5: J5.30, U2.17 (PH5)
PH6: J5.31, U2.18 (PH6)
PH7: J5.32, U2.27 (PH7)
PJ0: J6.17, U2.63 (PJ0)
PJ1: J6.18, U2.64 (PJ1)
PJ2: J6.19, U2.65 (PJ2)
PJ3: J6.20, U2.66 (PJ3)
PJ4: J6.21, U2.67 (PJ4)
PJ5: J6.22, U2.68 (PJ5)
PJ6: J6.23, U2.69 (PJ6)
PJ7: J6.24, U2.79 (PJ7)
PK0: J5.8, U2.89 (PK0)
PK1: J5.7, U2.88 (PK1)
PK2: J5.6, U2.87 (PK2)
PK3: J5.5, U2.86 (PK3)
PK4: J5.4, U2.85 (PK4)
PK5: J5.3, U2.84 (PK5)
PK6: J5.2, U2.83 (PK6)
PK7: J5.1, U2.82 (PK7)
PL0: J4.24, U2.35 (PL0)
PL1: J4.23, U2.36 (PL1)
PL2: J4.22, U2.37 (PL2)
PL3: J4.21, U2.38 (PL3)
PL4: J4.20, U2.39 (PL4)
PL5: J4.19, U2.40 (PL5)
PL6: J4.18, U2.41 (PL6)
PL7: J4.17, U2.42 (PL7)
RESET: C13.1, D4.2 (A), J3.5, JP2.2 (B), R11.2, U2.30 (~RESET)
RESET2: D1.2 (A), J2.5, R1.1, U1.24 (PC1/~RESET)
SCK2: J2.3, U1.15 (PB1)
aref: C14.2, C21.2, J6.15, U2.98 (AREF)

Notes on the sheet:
aref
gnd
status led
top-down
atmega2560
atmega 16U2
right
ISP 16U2
ISP 2560
upper
MCU bottom pinout
Pin Number Pin Name Mapped Pin Name 1 PG5 ( OC0B ) Digital pin 4 (PWM) 2 PE0 ( RXD0/PCINT8 ) Digital pin 0 (RX0) 3 PE1 ( TXD0 ) Digital pin 1 (TX0) 4 PE2 ( XCK0/AIN0 ) 5 PE3 ( OC3A/AIN1 ) Digital pin 5 (PWM) 6 PE4 ( OC3B/INT4 ) Digital pin 2 (PWM) 7 PE5 ( OC3C/INT5 ) Digital pin 3 (PWM) 8 PE6 ( T3/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
left

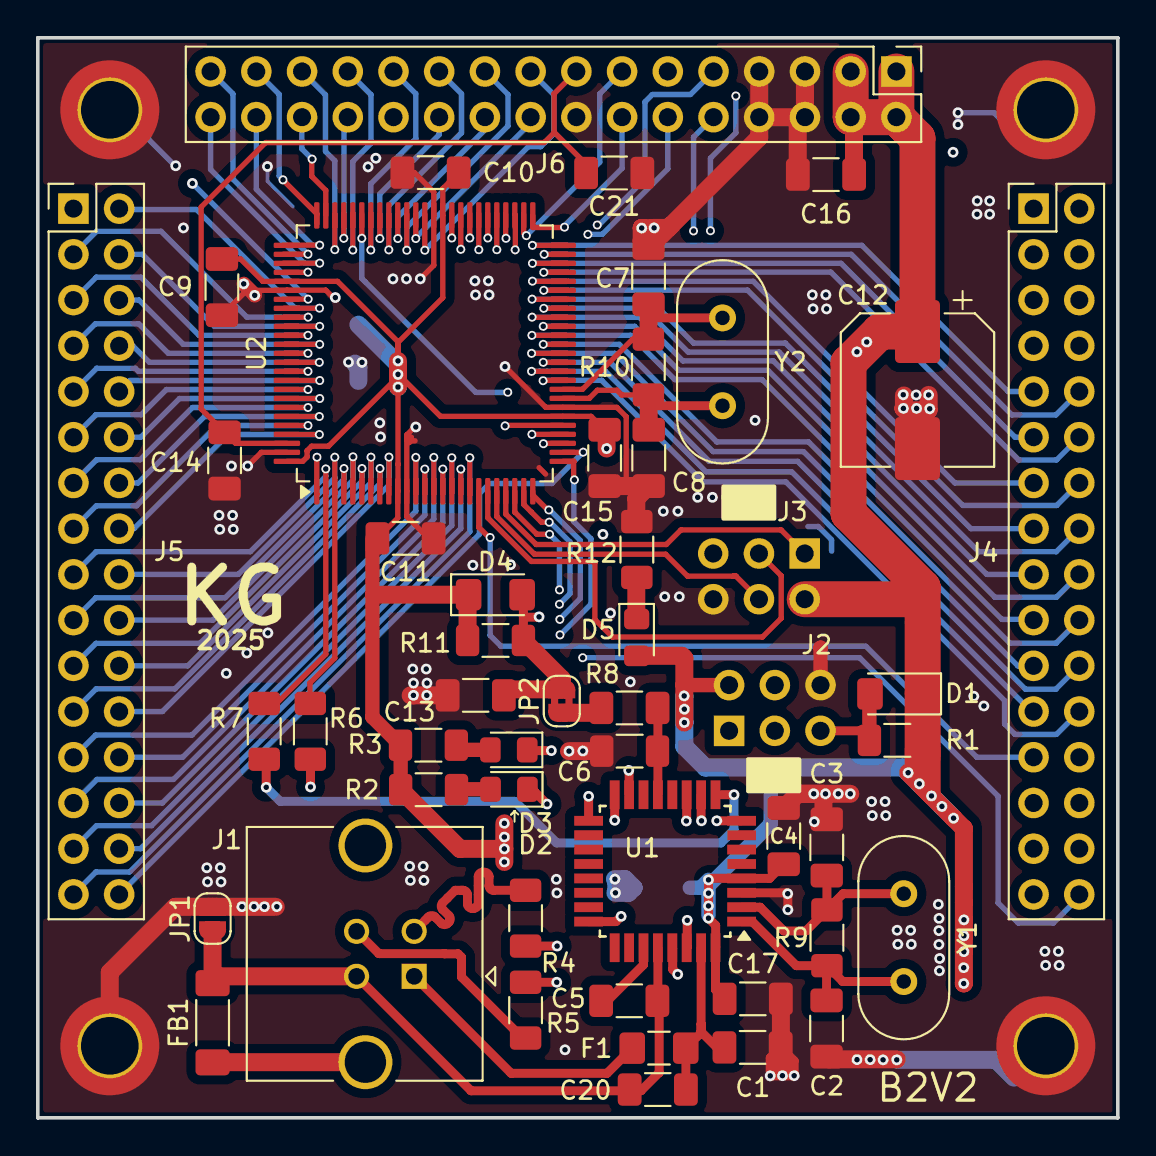
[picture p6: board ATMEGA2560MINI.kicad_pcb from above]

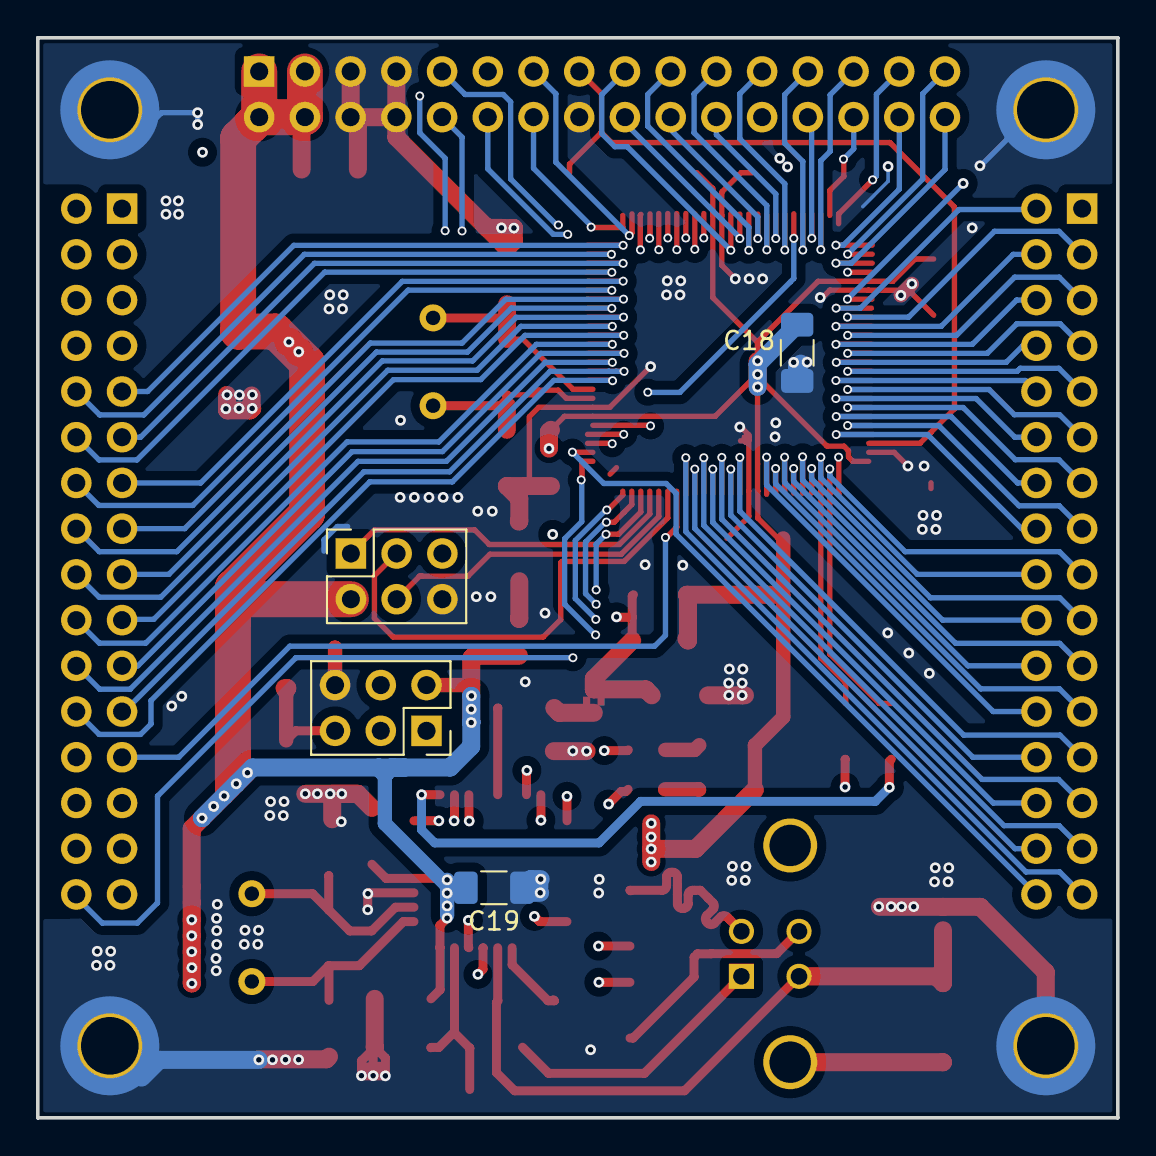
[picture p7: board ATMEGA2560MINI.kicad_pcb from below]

Board: 4 copper layers, 60.0 x 60.0 mm, 56 parts (4 on the bottom side), 116 nets.

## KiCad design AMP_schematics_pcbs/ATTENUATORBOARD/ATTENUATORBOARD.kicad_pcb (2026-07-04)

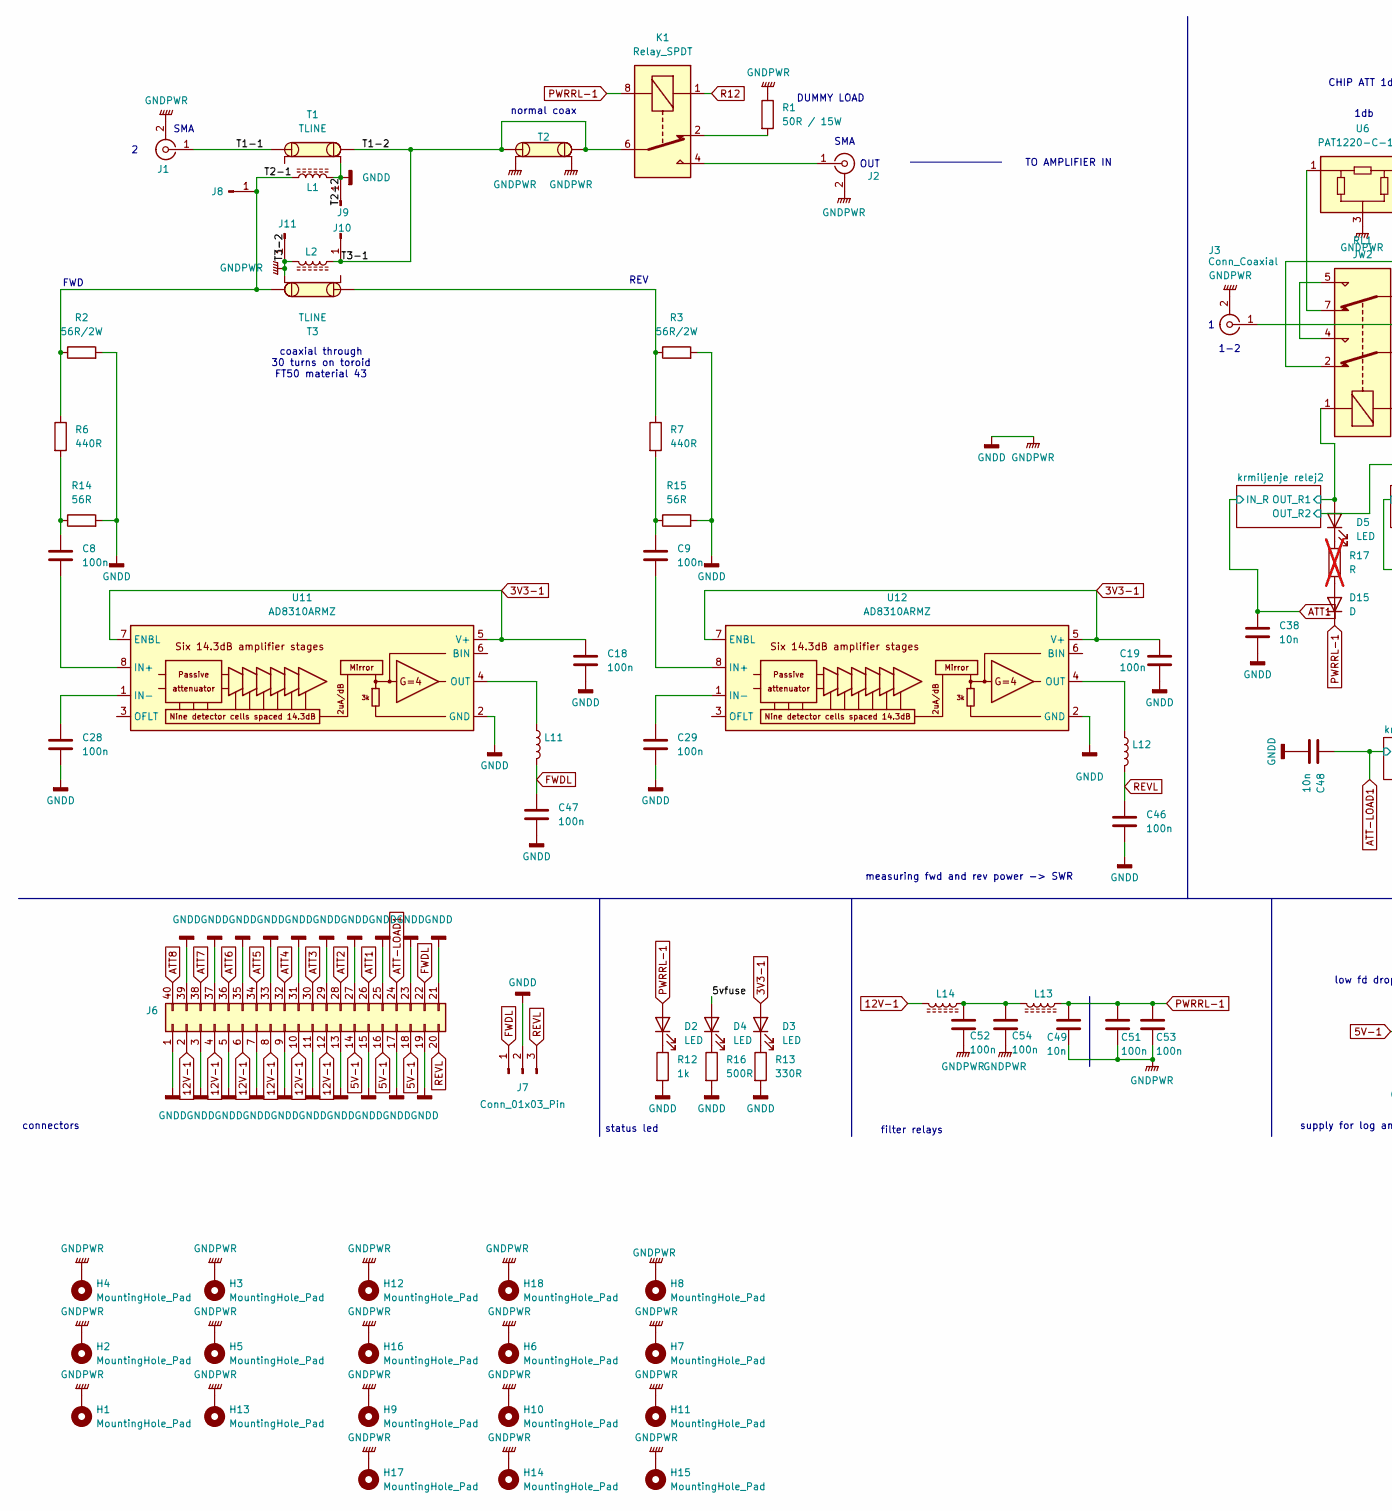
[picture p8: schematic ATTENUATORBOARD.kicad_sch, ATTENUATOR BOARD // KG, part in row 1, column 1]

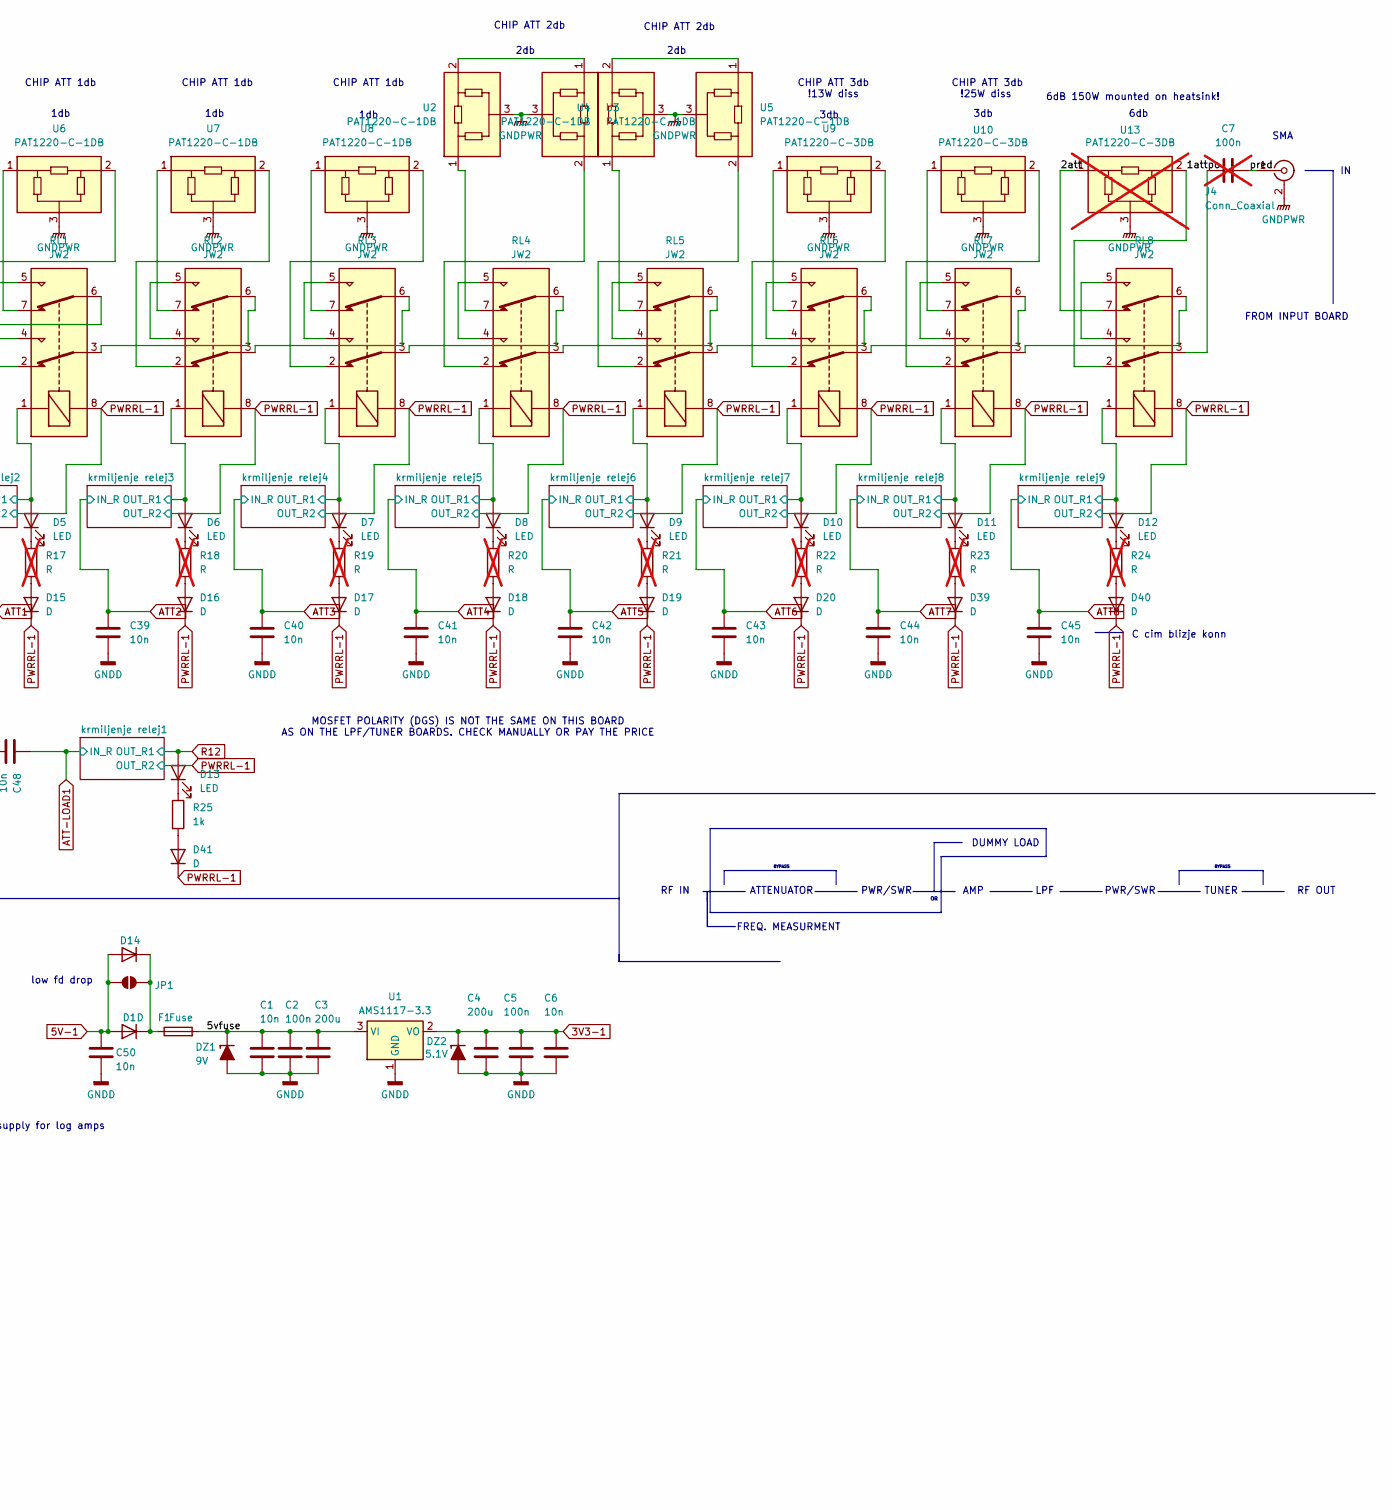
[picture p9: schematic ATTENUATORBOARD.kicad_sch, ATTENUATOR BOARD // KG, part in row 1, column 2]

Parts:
C1, C6, C38, C39, C40, C41, C42, C43, C44, C45, C48, C49, C50: 10n; C_1206_3216Metric_Pad1.33x1.80mm_HandSolder
C2, C5, C8, C9, C18, C19, C28, C29, C46, C47, C51, C52, C53, C54: 100n; C_1206_3216Metric_Pad1.33x1.80mm_HandSolder
C3, C4: 200u; CP_Elec_8x10
C7: 100n; not fitted
D1: D; D_P600_R-6_P12.70mm_Horizontal
D2, D3, D4, D5, D6, D7, D8, D9, D10, D11, D12, D13: LED; LED_0805_2012Metric_Pad1.15x1.40mm_HandSolder
D14, D15, D16, D17, D18, D19, D20, D39, D40, D41: D; D_1206_3216Metric_Pad1.42x1.75mm_HandSolder
DZ1: 9V; D_SOD-123_Zener
DZ2: 5.1V; D_SOD-123_Zener
F1: Fuse; Fuse_1206_3216Metric
H1, H2, H3, H4, H5, H13: MountingHole_Pad; MountingHole_4.3mm_M4_Pad_TopBottom
H6, H7, H8, H9, H10, H11, H12, H14, H15, H16, H17, H18: MountingHole_Pad; MountingHole_3.2mm_M3_Pad_TopBottom
J1, J2, J3, J4: Conn_Coaxial; SMA_Amphenol_132134_Vertical
J6: Conn_02x20_Counter_Clockwise; PinHeader_2x20_P2.54mm_Vertical
J7: Conn_01x03_Pin; PinHeader_1x03_P2.54mm_Vertical
J8, J9, J10, J11: Conn_01x01_Pin; PinSocket_1x01_P2.54mm_Vertical
JP1: SolderJumper_2_Open; SolderJumper-2_P1.3mm_Open_Pad1.0x1.5mm
K1: Relay_SPDT; Relay_SPDT_Panasonic_JW1_FormC
L1, L2: L_Ferrite
L11, L12: L; Ferrite_1206_3216Metric_Pad1.42x1.75mm_BigPads
L13, L14: L_Ferrite; Ferrite_1206_3216Metric_Pad1.22x1.90mm_BigPads
R1: 50R / 15W; TO-220-2_Horizontal_TabDown
R2, R3: 56R/2W; R_2512_6332Metric_Pad1.40x3.35mm_HandSolder
R6, R7: 440R; R_1206_3216Metric_Pad1.30x1.75mm_HandSolder
R12, R25: 1k; R_1206_3216Metric_Pad1.30x1.75mm_HandSolder
R13: 330R; R_1206_3216Metric_Pad1.30x1.75mm_HandSolder
R14, R15: 56R; R_1206_3216Metric_Pad1.30x1.75mm_HandSolder
R16: 500R; R_1206_3216Metric_Pad1.30x1.75mm_HandSolder
R17, R18, R19, R20, R21, R22, R23, R24: R; R_1206_3216Metric_Pad1.30x1.75mm_HandSolder; not fitted
RL1, RL2, RL3, RL4, RL5, RL6, RL7, RL8: JW2; Relay_DPDT_Panasonic_JW2
T1, T2, T3: TLINE
U1: AMS1117-3.3; SOT-223-3_TabPin2
U2, U3, U4, U5, U6, U7, U8: PAT1220-C-1DB; ATT-CHIP
U9, U10: PAT1220-C-3DB; ATT-CHIP
U11, U12: AD8310ARMZ; MSOP-8_3x3mm_P0.65mm
U13: PAT1220-C-3DB; ATT-CHIP; not fitted

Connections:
3V3-1: C4.1, C5.1, C6.1, C18.1, C19.1, D3.2 (A), DZ2.1 (K), U1.2 (VO), U11.5 (V+), U11.7 (ENBL), U12.5 (V+), U12.7 (ENBL)
5V-1: C50.1, D1.2 (A), D14.2 (A), J6.14, J6.16, J6.18, JP1.1 (A)
12V-1: J6.2, J6.4, J6.6, J6.8, J6.10, J6.12, L14.2
/1att: RL8.2, U13.2
/2att: RL8.7, U13.1
/5vfuse: C1.1, C2.1, C3.1, D4.2 (A), DZ1.1 (K), F1.2, U1.3 (VI)
/T1-1: J1.1 (In), T1.1
/T1-2: J10.1, K1.6, L2.1, T1.3, T2.1, T2.3
/T2-1: J8.1, L1.1, R2.1, R6.1, T3.3
/krmiljenje relej2/OUT_R1: D5.2 (A), RL1.1; also elsewhere on the board
/krmiljenje relej3/OUT_R1: D6.2 (A), RL2.1; also elsewhere on the board
/krmiljenje relej4/OUT_R1: D7.2 (A), RL3.1; also elsewhere on the board
/krmiljenje relej5/OUT_R1: D8.2 (A), RL4.1; also elsewhere on the board
/krmiljenje relej6/OUT_R1: D9.2 (A), RL5.1; also elsewhere on the board
/krmiljenje relej7/OUT_R1: D10.2 (A), RL6.1; also elsewhere on the board
/krmiljenje relej8/OUT_R1: D11.2 (A), RL7.1; also elsewhere on the board
/krmiljenje relej9/OUT_R1: D12.2 (A), RL8.1; also elsewhere on the board
/po: C7.1, RL8.3
/pred: C7.2, J4.1 (In)
ATT1: C38.1, J6.26; also elsewhere on the board
ATT2: C39.1, J6.28; also elsewhere on the board
ATT3: C40.1, J6.30; also elsewhere on the board
ATT4: C41.1, J6.32; also elsewhere on the board
ATT5: C42.1, J6.34; also elsewhere on the board
ATT6: C43.1, J6.36; also elsewhere on the board
ATT7: C44.1, J6.38; also elsewhere on the board
ATT8: C45.1, J6.40; also elsewhere on the board
ATT-LOAD1: C48.1, J6.24; also elsewhere on the board
FWDL: C47.1, J6.22, J7.1, L11.2
GNDD: C1.2, C2.2, C3.2, C4.2, C5.2, C6.2, C18.2, C19.2, C28.2, C29.2, C38.2, C39.2, C40.2, C41.2, C42.2, C43.2, C44.2, C45.2, C46.2, C47.2, C48.2, C49.2, C50.2, C51.2, C52.2, C53.2, C54.2, DZ1.2 (A), DZ2.2 (A), H1.1, H2.1, H3.1, H4.1, H5.1, H6.1, H7.1, H8.1, H9.1, H10.1, H11.1, H12.1, H13.1, H14.1, H15.1, H16.1, H17.1, H18.1, J1.2 (Ext), J2.2 (Ext), J3.2 (Ext), J4.2 (Ext), J6.1, J6.3, J6.5, J6.7, J6.9, J6.11, J6.13, J6.15, J6.17, J6.19, J6.21, J6.23, J6.25, J6.27, J6.29, J6.31, J6.33, J6.35, J6.37, J6.39, J7.2, J9.1, J11.1, L1.2, L2.2, R1.1, R2.2, R3.2, R12.2, R13.2, R14.2, R15.2, R16.2, T1.4, T2.2, T2.4, T3.4, U1.1 (GND), U2.3, U3.3, U4.3, U5.3, U6.3, U7.3, U8.3, U9.3, U10.3, U11.2 (GND), U12.2 (GND), U13.3; also elsewhere on the board
unnamed: C8.1, R6.2, R14.1
unnamed: C9.1, R7.2, R15.1
unnamed: C52.1, C54.1, L13.2, L14.1
unnamed: D1.1 (K), D14.1 (K), F1.1, JP1.2 (B)
unnamed: D2.1 (K), R12.1
unnamed: D3.1 (K), R13.1
unnamed: D4.1 (K), R16.1
unnamed: D5.1 (K), R17.1
unnamed: D6.1 (K), R18.1
unnamed: D7.1 (K), R19.1
unnamed: D8.1 (K), R20.1
unnamed: D9.1 (K), R21.1
unnamed: D10.1 (K), R22.1
unnamed: D11.1 (K), R23.1
unnamed: D12.1 (K), R24.1
unnamed: D13.1 (K), R25.1
unnamed: D15.2 (A), R17.2
unnamed: D16.2 (A), R18.2
unnamed: D17.2 (A), R19.2
unnamed: D18.2 (A), R20.2
unnamed: D19.2 (A), R21.2
unnamed: D20.2 (A), R22.2
unnamed: D39.2 (A), R23.2
unnamed: D40.2 (A), R24.2
unnamed: D41.2 (A), R25.2
unnamed: J2.1 (In), K1.4
unnamed: J3.1 (In), RL1.6
unnamed: K1.2, R1.2
unnamed: R3.1, R7.1, T3.1
unnamed: RL1.2, U6.2
unnamed: RL1.3, RL2.6
unnamed: RL1.4, RL1.5
unnamed: RL1.7, U6.1
unnamed: RL2.2, U7.2
unnamed: RL2.3, RL3.6
unnamed: RL2.4, RL2.5
unnamed: RL2.7, U7.1
unnamed: RL3.2, U8.2
unnamed: RL3.3, RL4.6
unnamed: RL3.4, RL3.5
unnamed: RL3.7, U8.1
unnamed: RL4.2, U3.2
unnamed: RL4.3, RL5.6
unnamed: RL4.4, RL4.5
unnamed: RL4.7, U2.1
unnamed: RL5.2, U5.2
unnamed: RL5.3, RL6.6
unnamed: RL5.4, RL5.5
unnamed: RL5.7, U4.1
unnamed: RL6.2, U9.2
unnamed: RL6.3, RL7.6
unnamed: RL6.4, RL6.5
unnamed: RL6.7, U9.1
unnamed: RL7.2, U10.2
unnamed: RL7.3, RL8.6
unnamed: RL7.4, RL7.5
unnamed: RL7.7, U10.1
unnamed: RL8.4, RL8.5
unnamed: U2.2, U3.1
unnamed: U4.2, U5.1
unnamed: C8.2, U11.8 (IN+)
unnamed: C28.1, U11.1 (IN-)
unnamed: L11.1, U11.4 (OUT)
unnamed: C9.2, U12.8 (IN+)
unnamed: C29.1, U12.1 (IN-)
unnamed: L12.1, U12.4 (OUT)
PWRRL-1: C49.1, C51.1, C53.1, D2.2 (A), D15.1 (K), D16.1 (K), D17.1 (K), D18.1 (K), D19.1 (K), D20.1 (K), D39.1 (K), D40.1 (K), D41.1 (K), K1.8, L13.1, RL1.8, RL2.8, RL3.8, RL4.8, RL5.8, RL6.8, RL7.8, RL8.8; also elsewhere on the board
R12: D13.2 (A), K1.1; also elsewhere on the board
REVL: C46.1, J6.20, J7.3, L12.2

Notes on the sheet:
RF OUT
TO AMPLIFIER IN
RF IN
CHIP ATT 3db
CHIP ATT 1db
3db
FREQ. MEASURMENT
coaxial through 30 turns on toroid FT50 material 43
!13W diss
1-2
6db
BYPASS
ATTENUATOR
SMA
AMP
CHIP ATT 2db
filter relays
1db
REV
measuring fwd and rev power -> SWR
connectors
PWR/SWR
6dB 150W mounted on heatsink!
normal coax
status led
TUNER
DUMMY LOAD
LPF
FROM INPUT BOARD
OUT
!25W diss
FWD
low fd drop
2db
C cim blizje konn
supply for log amps
MOSFET POLARITY (DGS) IS NOT THE SAME ON THIS BOARD AS ON THE LPF/TUNER BOARDS. CHECK MANUALLY OR PAY THE PRICE

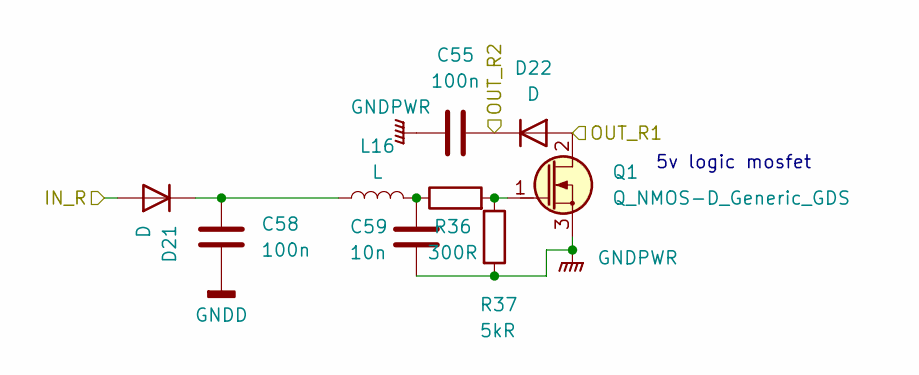
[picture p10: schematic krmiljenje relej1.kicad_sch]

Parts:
C55, C58: 100n; C_1206_3216Metric_Pad1.33x1.80mm_HandSolder
C59: 10n; C_1206_3216Metric_Pad1.33x1.80mm_HandSolder
D21, D22: D; D_1206_3216Metric_Pad1.42x1.75mm_HandSolder
L16: L; Ferrite_1206_3216Metric_Pad1.42x1.75mm_BigPads
Q1: Q_NMOS-D_Generic_GDS; TSOT-23_HandSoldering
R36: 300R; R_1206_3216Metric_Pad1.30x1.75mm_HandSolder
R37: 5kR; R_1206_3216Metric_Pad1.30x1.75mm_HandSolder

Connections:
ATT-LOAD1: D21.2 (A); also elsewhere on the board
GNDD: C55.2, C58.2, C59.2, Q1.3 (S), R37.2; also elsewhere on the board
unnamed: C59.1, L16.2, R36.1
unnamed: C58.1, D21.1 (K), L16.1
unnamed: Q1.1 (G), R36.2, R37.1
PWRRL-1: C55.1, D22.1 (K); also elsewhere on the board
R12: D22.2 (A), Q1.2 (D); also elsewhere on the board

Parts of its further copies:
C56, C57, C60, C62, C64, C66, C67, C69, C70, C72, C73, C75, C76, C78, C79, C81: 100n; C_1206_3216Metric_Pad1.33x1.80mm_HandSolder
C61, C63, C65, C68, C71, C74, C77, C80: 10n; C_1206_3216Metric_Pad1.33x1.80mm_HandSolder
D23, D24, D25, D26, D27, D28, D29, D30, D31, D32, D33, D34, D35, D36, D37, D38: D; D_1206_3216Metric_Pad1.42x1.75mm_HandSolder
L17, L18, L19, L20, L21, L22, L23, L24: L; Ferrite_1206_3216Metric_Pad1.42x1.75mm_BigPads
Q2, Q3, Q4, Q5, Q6, Q7, Q8, Q9: Q_NMOS-D_Generic_GDS; TSOT-23_HandSoldering
R38, R40, R42, R44, R46, R48, R50, R52: 300R; R_1206_3216Metric_Pad1.30x1.75mm_HandSolder
R39, R41, R43, R45, R47, R49, R51, R53: 5kR; R_1206_3216Metric_Pad1.30x1.75mm_HandSolder

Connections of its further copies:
/krmiljenje relej2/OUT_R1: D24.2 (A), Q2.2 (D); also elsewhere on the board
/krmiljenje relej3/OUT_R1: D26.2 (A), Q3.2 (D); also elsewhere on the board
/krmiljenje relej4/OUT_R1: D28.2 (A), Q4.2 (D); also elsewhere on the board
/krmiljenje relej5/OUT_R1: D30.2 (A), Q5.2 (D); also elsewhere on the board
/krmiljenje relej6/OUT_R1: D32.2 (A), Q6.2 (D); also elsewhere on the board
/krmiljenje relej7/OUT_R1: D34.2 (A), Q7.2 (D); also elsewhere on the board
/krmiljenje relej8/OUT_R1: D36.2 (A), Q8.2 (D); also elsewhere on the board
/krmiljenje relej9/OUT_R1: D38.2 (A), Q9.2 (D); also elsewhere on the board
ATT1: D23.2 (A); also elsewhere on the board
ATT2: D25.2 (A); also elsewhere on the board
ATT3: D27.2 (A); also elsewhere on the board
ATT4: D29.2 (A); also elsewhere on the board
ATT5: D31.2 (A); also elsewhere on the board
ATT6: D33.2 (A); also elsewhere on the board
ATT7: D35.2 (A); also elsewhere on the board
ATT8: D37.2 (A); also elsewhere on the board
GNDD: C56.2, C57.2, C60.2, C61.2, C62.2, C63.2, C64.2, C65.2, C66.2, C67.2, C68.2, C69.2, C70.2, C71.2, C72.2, C73.2, C74.2, C75.2, C76.2, C77.2, C78.2, C79.2, C80.2, C81.2, Q2.3 (S), Q3.3 (S), Q4.3 (S), Q5.3 (S), Q6.3 (S), Q7.3 (S), Q8.3 (S), Q9.3 (S), R39.2, R41.2, R43.2, R45.2, R47.2, R49.2, R51.2, R53.2; also elsewhere on the board
unnamed: C61.1, L17.2, R38.1
unnamed: C63.1, L18.2, R40.1
unnamed: C65.1, L19.2, R42.1
unnamed: C68.1, L20.2, R44.1
unnamed: C71.1, L21.2, R46.1
unnamed: C74.1, L22.2, R48.1
unnamed: C77.1, L23.2, R50.1
unnamed: C80.1, L24.2, R52.1
unnamed: C60.1, D23.1 (K), L17.1
unnamed: C62.1, D25.1 (K), L18.1
unnamed: C64.1, D27.1 (K), L19.1
unnamed: C67.1, D29.1 (K), L20.1
unnamed: C70.1, D31.1 (K), L21.1
unnamed: C73.1, D33.1 (K), L22.1
unnamed: C76.1, D35.1 (K), L23.1
unnamed: C79.1, D37.1 (K), L24.1
unnamed: Q2.1 (G), R38.2, R39.1
unnamed: Q3.1 (G), R40.2, R41.1
unnamed: Q4.1 (G), R42.2, R43.1
unnamed: Q5.1 (G), R44.2, R45.1
unnamed: Q6.1 (G), R46.2, R47.1
unnamed: Q7.1 (G), R48.2, R49.1
unnamed: Q8.1 (G), R50.2, R51.1
unnamed: Q9.1 (G), R52.2, R53.1
PWRRL-1: C56.1, C57.1, C66.1, C69.1, C72.1, C75.1, C78.1, C81.1, D24.1 (K), D26.1 (K), D28.1 (K), D30.1 (K), D32.1 (K), D34.1 (K), D36.1 (K), D38.1 (K); also elsewhere on the board

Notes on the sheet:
5v logic mosfet

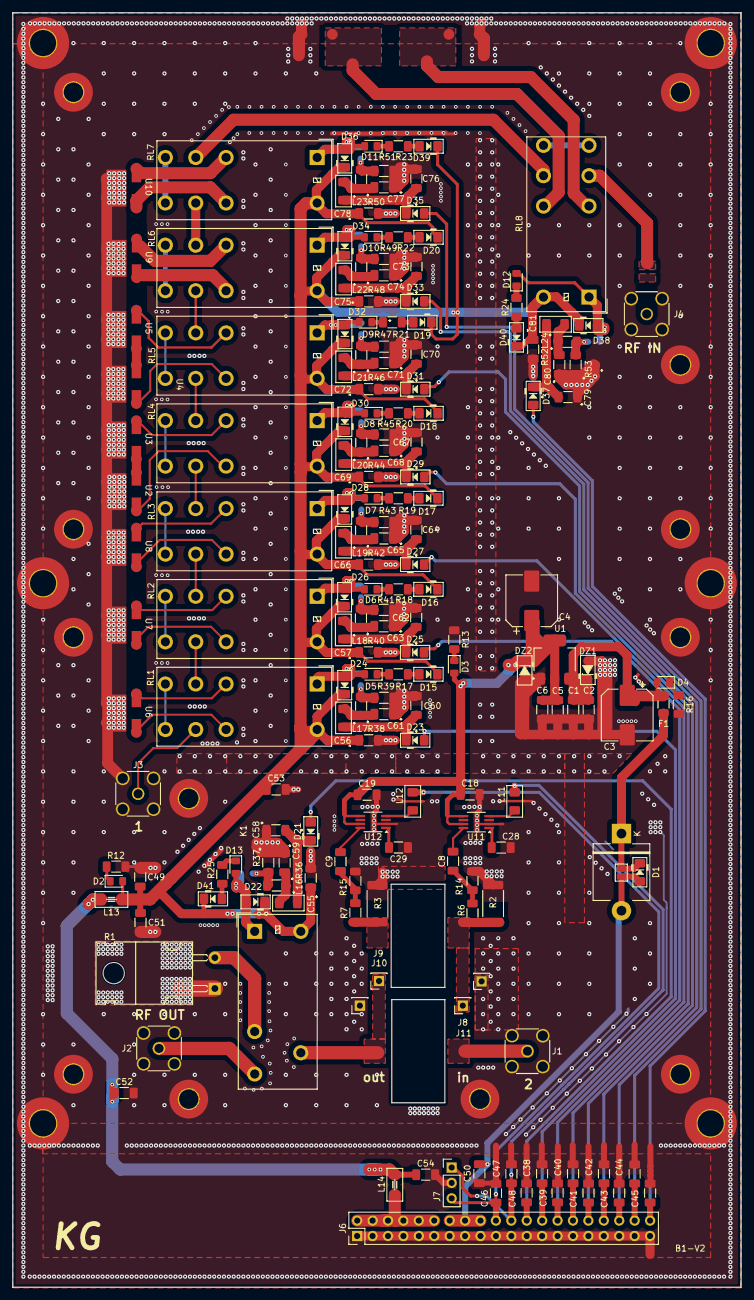
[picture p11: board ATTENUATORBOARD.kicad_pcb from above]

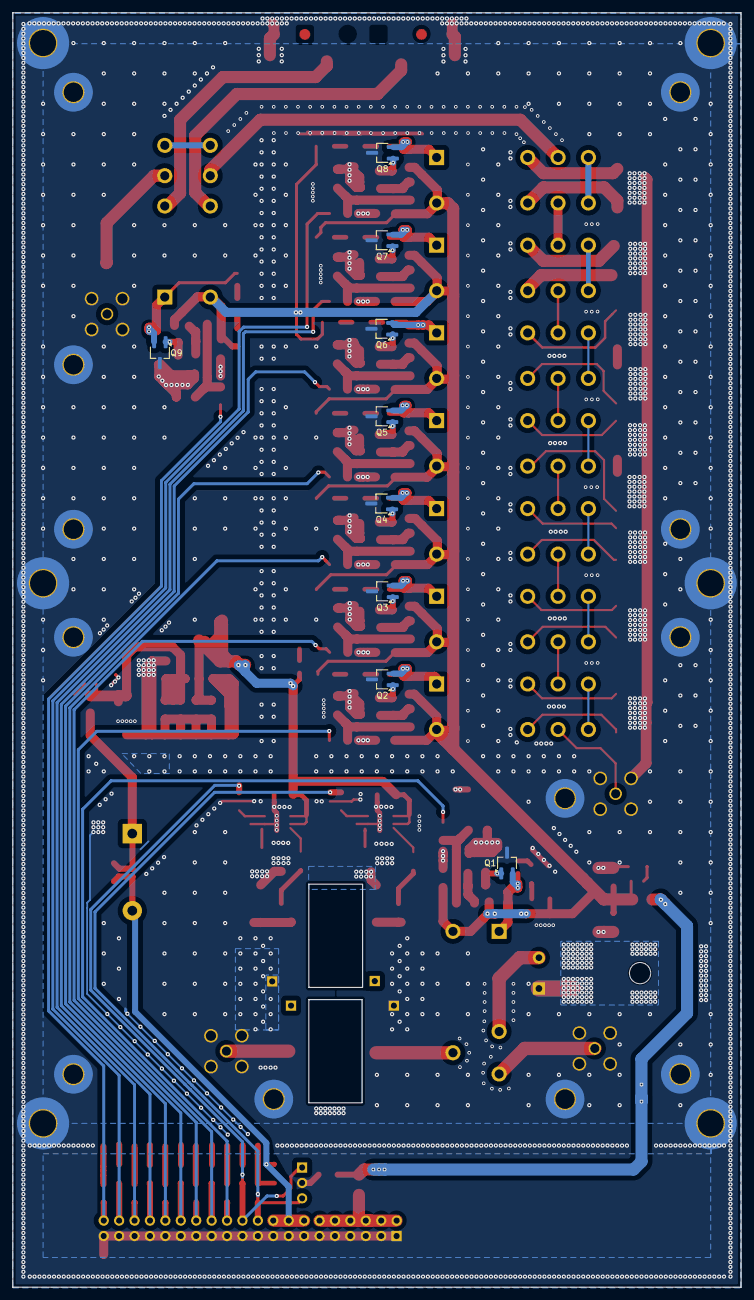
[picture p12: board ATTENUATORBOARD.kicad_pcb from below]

Board: 4 copper layers, 120.0 x 210.0 mm, 209 parts (9 on the bottom side), 121 nets.

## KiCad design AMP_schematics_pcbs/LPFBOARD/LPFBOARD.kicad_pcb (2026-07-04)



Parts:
C1, C6, C15, C20, C61: 10n; C_1206_3216Metric_Pad1.33x1.80mm_HandSolder
C2, C5, C8, C9, C16, C17, C18, C19, C21, C22, C24, C55, C56, C57, C58, C59, C60, C62: 100n; C_1206_3216Metric_Pad1.33x1.80mm_HandSolder
C3, C4: 200u; CP_Elec_8x10
C7, C10, C11, C12, C13, C14, C23, C63, C64, C65, C66, C67, C68, C69, C70, C71, C72, C73, C74, C75, C76, C77, C78, C79, C80, C81, C82, C83, C84, C85: C; C_2220_5750Metric_Pad1.97x5.40mm_HandSolder
D1: D; D_P600_R-6_P12.70mm_Horizontal
D22: D; D_1206_3216Metric_Pad1.42x1.75mm_HandSolder
D23, D24: LED; LED_0805_2012Metric_Pad1.15x1.40mm_HandSolder
DZ1: 9V; D_SOD-123_Zener
DZ2: 5.1V; D_SOD-123_Zener
DZ3: 5.1V; D_A-405_P7.62mm_Horizontal
F1: Fuse; Fuse_1206_3216Metric
H1, H2, H3, H4, H5, H6: MountingHole_Pad; MountingHole_4.3mm_M4_Pad_TopBottom
H7, H8, H9, H10, H11, H12, H13, H14: MountingHole_Pad; MountingHole_3.2mm_M3_Pad_TopBottom
J1, J4: Conn_Coaxial; SMA_Amphenol_132134_Vertical
J2: Conn_01x03_Pin; PinSocket_1x03_P2.54mm_Vertical
J6, J7: Conn_02x20_Counter_Clockwise; PinHeader_2x20_P2.54mm_Vertical
J8: Conn_02x10_Odd_Even; PinHeader_2x10_P2.54mm_Vertical
J9, J10, J11, J12: Conn_01x01_Pin; PinSocket_1x01_P2.54mm_Vertical
JP1: SolderJumper_2_Open; SolderJumper-2_P1.3mm_Open_Pad1.0x1.5mm
K1, K2, K3, K4, K5, K6, K7, K8, K9, K10: Relay_SPDT-jw1; Relay_SPDT_Panasonic_JW1_FormC
L1, L2: L_Ferrite
L3, L4, L21, L22, L23, L24, L25, L26, L27, L28: L_Ferrite; T80_footprint
L5, L6, L19, L20: L_Ferrite; Ferrite_1206_3216Metric_Pad1.42x1.75mm_BigPads
L17, L18: L; Ferrite_1206_3216Metric_Pad1.42x1.75mm_BigPads
R1, R32: 1k; R_1206_3216Metric_Pad1.30x1.75mm_HandSolder
R2, R3: 56R/2W; R_2512_6332Metric_Pad1.40x3.35mm_HandSolder
R6, R7: 440R; R_1206_3216Metric_Pad1.30x1.75mm_HandSolder
R29, R30: 56R; R_1206_3216Metric_Pad1.30x1.75mm_HandSolder
R31: 500R; R_1206_3216Metric_Pad1.30x1.75mm_HandSolder
T1, T2, T3: TLINE
U1: AMS1117-3.3; SOT-223-3_TabPin2
U11, U12: AD8310ARMZ; MSOP-8_3x3mm_P0.65mm

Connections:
3V3-2: C4.1, C5.1, C6.1, C57.1, C60.1, DZ2.1 (K), U1.2 (VO), U11.5 (V+), U11.7 (ENBL), U12.5 (V+), U12.7 (ENBL)
5V-2: C61.1, C62.1, D1.2 (A), D22.2 (A), J7.2, J7.4, J7.6, JP1.1 (A)
12V-2: J7.8, J7.10, J7.12, J7.14, J7.16, J7.18, J7.20, J7.22, J7.24, J7.26, J7.28, J7.30, J7.32, J7.34, L5.2, L6.2, L19.2, L20.2, R1.1
/1s: C70.2, L3.2, L24.1
/2s: C69.2, L4.2, L25.1
/3s: C68.2, L21.2, L26.1
/4s: C67.2, L22.2, L27.1
/5s: C66.1, L23.2, L28.1
/5vfuse: C1.1, C2.1, C3.1, D23.2 (A), DZ1.1 (K), F1.2, U1.3 (VI)
/10: C10.2, K1.4, L3.1
/11: C10.1, C71.2
/12: C70.1, C80.2
/13: C14.1, C81.2
/14: C14.2, K6.4, L24.2
/20: C7.2, K2.4, L4.1
/21: C7.1, C72.2
/22: C69.1, C79.2
/23: C23.1, C82.2
/24: C23.2, K7.4, L25.2
/30: C11.2, K3.4, L21.1
/31: C11.1, C73.2
/32: C68.1, C78.2
/33: C63.1, C83.2
/34: C63.2, K8.4, L26.2
/40: C12.2, K4.4, L22.1
/41: C12.1, C74.2
/42: C67.1, C77.2
/43: C64.1, C84.2
/44: C64.2, K9.4, L27.2
/50: C13.2, K5.4, L23.1
/51: C13.1, C75.2
/52: C66.2, C76.2
/53: C65.1, C85.2
/54: C65.2, K10.4, L28.2
/R1B1: K1.1; also elsewhere on the board
/R1B2: K2.1; also elsewhere on the board
/R1B3: K3.1; also elsewhere on the board
/R1B4: K4.1; also elsewhere on the board
/R1B5: K5.1; also elsewhere on the board
/R2B1: K6.8; also elsewhere on the board
/R2B2: K7.8; also elsewhere on the board
/R2B3: K8.8; also elsewhere on the board
/R2B4: K9.8; also elsewhere on the board
/R2B5: K10.8; also elsewhere on the board
/T1-1: J1.1 (In), T1.1
/T1-2: J12.1, L2.1, T1.3, T2.1, T2.3
/T2-1: J9.1, L1.1, R2.1, R6.1, T3.3
/in: J4.1 (In), K1.6, K2.6, K3.6, K4.6, K5.6
/out: K6.6, K7.6, K8.6, K9.6, K10.6
B1: J6.32; also elsewhere on the board
B2: J6.34; also elsewhere on the board
B3: J6.36; also elsewhere on the board
B4: J6.38; also elsewhere on the board
B5: J6.40; also elsewhere on the board
CTR1: J6.30, J8.12
CTR2: J6.28, J8.14
CTR3: J6.26, J8.16
CTR4: J6.24, J8.18
CTR5: J6.22, J8.20
CTR6: J6.2, J8.19
CTR7: J6.4, J8.17
CTR8: J6.6, J8.1
CTR9: J6.8, J8.3
CTR10: J6.10, J8.5
CTR11: J6.12, J8.7
CTR12: J6.14, J8.9
CTR13: J6.16, J8.2
CTR14: J6.18, J8.4
CTR15: J6.20, J8.10
FWDH: C56.1, J7.40, L17.2
GNDD: C1.2, C2.2, C3.2, C4.2, C5.2, C6.2, C15.2, C16.2, C17.2, C18.2, C19.2, C20.2, C21.2, C22.2, C24.2, C55.2, C56.2, C57.2, C58.2, C59.2, C60.2, C61.2, C62.2, C71.1, C72.1, C73.1, C74.1, C75.1, C76.1, C77.1, C78.1, C79.1, C80.1, C81.1, C82.1, C83.1, C84.1, C85.1, DZ1.2 (A), DZ2.2 (A), DZ3.2 (A), H1.1, H2.1, H3.1, H4.1, H5.1, H6.1, H7.1, H8.1, H9.1, H10.1, H11.1, H12.1, H13.1, H14.1, J1.2 (Ext), J2.2, J4.2 (Ext), J6.1, J6.3, J6.5, J6.7, J6.9, J6.11, J6.13, J6.15, J6.17, J6.19, J6.21, J6.23, J6.25, J6.27, J6.29, J6.31, J6.33, J6.35, J6.37, J6.39, J7.1, J7.3, J7.5, J7.7, J7.9, J7.11, J7.13, J7.15, J7.17, J7.19, J7.21, J7.23, J7.25, J7.27, J7.29, J7.31, J7.33, J7.35, J7.37, J7.39, J10.1, J11.1, L1.2, L2.2, R2.2, R3.2, R29.2, R30.2, R31.2, R32.2, T1.4, T2.2, T2.4, T3.4, U1.1 (GND), U11.2 (GND), U12.2 (GND); also elsewhere on the board
unnamed: C8.1, R6.2, R29.1
unnamed: C9.1, R7.2, R30.1
unnamed: D1.1 (K), D22.1 (K), F1.1, JP1.2 (B)
unnamed: D23.1 (K), R31.1
unnamed: D24.1 (K), R32.1
unnamed: DZ3.1 (K), J2.3, R1.2
unnamed: R3.1, R7.1, T3.1
unnamed: C8.2, U11.8 (IN+)
unnamed: C55.1, U11.1 (IN-)
unnamed: L17.1, U11.4 (OUT)
unnamed: C9.2, U12.8 (IN+)
unnamed: C58.1, U12.1 (IN-)
unnamed: L18.1, U12.4 (OUT)
PWRRL: C20.1, C21.1, C22.1, C24.1, D24.2 (A), J8.6, J8.8, J8.11, J8.13, J8.15, L19.1, L20.1
PWRRL2: C15.1, C16.1, C17.1, C18.1, C19.1, K1.8, K2.8, K3.8, K4.8, K5.8, K6.1, K7.1, K8.1, K9.1, K10.1, L5.1, L6.1; also elsewhere on the board
REVH: C59.1, J7.38, L18.2
TEMP-NOTER: J2.1, J7.36

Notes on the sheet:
BYPASS
DUMMY LOAD
temp inner
MOSFET POLARITY (DGS) IS NOT THE SAME ON THIS BOARD AS ON THE ATTENUATOR BOARD. CHECK MANUALLY OR PAY THE PRICE
FWD
ATTENUATOR
PWR/SWR
LPF
normal coax
RF IN
connectors
supply relay
FROM AMP
REV
FREQ. MEASURMENT
supply log amp
status led
AMP
FROM FILTERS
SMA
low fw drop
measuring fwd and rev power -> SWR
RF OUT
TUNER
see excel tables for values...
TO PWR/SWR
TO TUNER


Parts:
C25, C26: 100n; C_1206_3216Metric_Pad1.33x1.80mm_HandSolder
C27: 10n; C_1206_3216Metric_Pad1.33x1.80mm_HandSolder
D2, D3: D; D_1206_3216Metric_Pad1.42x1.75mm_HandSolder
L7: L; Ferrite_1206_3216Metric_Pad1.42x1.75mm_BigPads
Q1: Q_NMOS-D_Generic_GDS; TSOT-23_HandSoldering
R9: 300R; R_1206_3216Metric_Pad1.30x1.75mm_HandSolder
R10: 5kR; R_1206_3216Metric_Pad1.30x1.75mm_HandSolder

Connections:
/R1B1: D2.2 (A), Q1.3 (D); also elsewhere on the board
B1: D3.2 (A); also elsewhere on the board
GNDD: C25.2, C26.2, C27.2, Q1.2 (S), R10.2; also elsewhere on the board
unnamed: C27.1, L7.2, R9.1
unnamed: C26.1, D3.1 (K), L7.1
unnamed: Q1.1 (G), R9.2, R10.1
PWRRL2: C25.1, D2.1 (K); also elsewhere on the board

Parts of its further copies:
C28, C29, C31, C32, C34, C35, C37, C38, C40, C41, C43, C44, C46, C47, C49, C50, C52, C53: 100n; C_1206_3216Metric_Pad1.33x1.80mm_HandSolder
C30, C33, C36, C39, C42, C45, C48, C51, C54: 10n; C_1206_3216Metric_Pad1.33x1.80mm_HandSolder
D4, D5, D6, D7, D8, D9, D10, D11, D12, D13, D14, D15, D16, D17, D18, D19, D20, D21: D; D_1206_3216Metric_Pad1.42x1.75mm_HandSolder
L8, L9, L10, L11, L12, L13, L14, L15, L16: L; Ferrite_1206_3216Metric_Pad1.42x1.75mm_BigPads
Q2, Q3, Q4, Q5, Q6, Q7, Q8, Q9, Q10: Q_NMOS-D_Generic_GDS; TSOT-23_HandSoldering
R11, R13, R15, R17, R19, R21, R23, R25, R27: 300R; R_1206_3216Metric_Pad1.30x1.75mm_HandSolder
R12, R14, R16, R18, R20, R22, R24, R26, R28: 5kR; R_1206_3216Metric_Pad1.30x1.75mm_HandSolder

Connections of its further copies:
/R1B2: D6.2 (A), Q3.3 (D); also elsewhere on the board
/R1B3: D10.2 (A), Q5.3 (D); also elsewhere on the board
/R1B4: D14.2 (A), Q7.3 (D); also elsewhere on the board
/R1B5: D18.2 (A), Q9.3 (D); also elsewhere on the board
/R2B1: D4.2 (A), Q2.3 (D); also elsewhere on the board
/R2B2: D8.2 (A), Q4.3 (D); also elsewhere on the board
/R2B3: D12.2 (A), Q6.3 (D); also elsewhere on the board
/R2B4: D16.2 (A), Q8.3 (D); also elsewhere on the board
/R2B5: D20.2 (A), Q10.3 (D); also elsewhere on the board
B1: D5.2 (A); also elsewhere on the board
B2: D7.2 (A), D9.2 (A); also elsewhere on the board
B3: D11.2 (A), D13.2 (A); also elsewhere on the board
B4: D15.2 (A), D17.2 (A); also elsewhere on the board
B5: D19.2 (A), D21.2 (A); also elsewhere on the board
GNDD: C28.2, C29.2, C30.2, C31.2, C32.2, C33.2, C34.2, C35.2, C36.2, C37.2, C38.2, C39.2, C40.2, C41.2, C42.2, C43.2, C44.2, C45.2, C46.2, C47.2, C48.2, C49.2, C50.2, C51.2, C52.2, C53.2, C54.2, Q2.2 (S), Q3.2 (S), Q4.2 (S), Q5.2 (S), Q6.2 (S), Q7.2 (S), Q8.2 (S), Q9.2 (S), Q10.2 (S), R12.2, R14.2, R16.2, R18.2, R20.2, R22.2, R24.2, R26.2, R28.2; also elsewhere on the board
unnamed: C30.1, L8.2, R11.1
unnamed: C33.1, L9.2, R13.1
unnamed: C36.1, L10.2, R15.1
unnamed: C39.1, L11.2, R17.1
unnamed: C42.1, L12.2, R19.1
unnamed: C45.1, L13.2, R21.1
unnamed: C48.1, L14.2, R23.1
unnamed: C51.1, L15.2, R25.1
unnamed: C54.1, L16.2, R27.1
unnamed: C29.1, D5.1 (K), L8.1
unnamed: C32.1, D7.1 (K), L9.1
unnamed: C35.1, D9.1 (K), L10.1
unnamed: C38.1, D11.1 (K), L11.1
unnamed: C41.1, D13.1 (K), L12.1
unnamed: C44.1, D15.1 (K), L13.1
unnamed: C47.1, D17.1 (K), L14.1
unnamed: C50.1, D19.1 (K), L15.1
unnamed: C53.1, D21.1 (K), L16.1
unnamed: Q2.1 (G), R11.2, R12.1
unnamed: Q3.1 (G), R13.2, R14.1
unnamed: Q4.1 (G), R15.2, R16.1
unnamed: Q5.1 (G), R17.2, R18.1
unnamed: Q6.1 (G), R19.2, R20.1
unnamed: Q7.1 (G), R21.2, R22.1
unnamed: Q8.1 (G), R23.2, R24.1
unnamed: Q9.1 (G), R25.2, R26.1
unnamed: Q10.1 (G), R27.2, R28.1
PWRRL2: C28.1, C31.1, C34.1, C37.1, C40.1, C43.1, C46.1, C49.1, C52.1, D4.1 (K), D6.1 (K), D8.1 (K), D10.1 (K), D12.1 (K), D14.1 (K), D16.1 (K), D18.1 (K), D20.1 (K); also elsewhere on the board

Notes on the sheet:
5v logic mosfet

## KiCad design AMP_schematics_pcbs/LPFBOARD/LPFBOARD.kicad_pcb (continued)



Board: 4 copper layers, 120.0 x 210.0 mm, 216 parts (77 on the bottom side), 116 nets.

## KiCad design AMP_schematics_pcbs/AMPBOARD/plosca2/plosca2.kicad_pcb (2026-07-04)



Board: 2 copper layers, 60.0 x 23.0 mm, 10 parts (3 on the bottom side), 4 nets.

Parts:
C5, C7: C; C_1206_3216Metric_Pad1.33x1.80mm_HandSolder
H1, H2: MountingHole_Pad; MountingHole_3.2mm_M3_Pad_TopBottom
J1: Conn_Coaxial; SMA-smd
J2, J3, J4, J5: Conn_01x01_Pin; PinSocket_1x01_P2.54mm_Vertical
T1: Transformer_1P_1S; trans-mali

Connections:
/in: J1.1 (In), T1.1 (AA)
/t1: J2.1, T1.4 (SB)
/t2: J3.1, T1.3 (SA)
GNDPWR: C5.1, C7.2, H1.1, H2.1, J1.2 (Ext), T1.2 (AB)

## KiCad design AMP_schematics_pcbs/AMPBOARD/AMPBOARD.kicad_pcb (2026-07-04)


Board: 4 copper layers, 120.0 x 210.0 mm, 140 parts (0 on the bottom side), 55 nets.

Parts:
C1, C2, C3, C6, C7, C9, C10, C11, C45, C46: C; C_2220_5750Metric_Pad1.97x5.40mm_HandSolder
C5, C13: 100p; C_2220_5750Metric_Pad1.97x5.40mm_HandSolder
C14, C15, C25, C29, C30, C32, C36, C38, C41, C42, C43, C44, C48, C49, C50, C52, C53, C56, C58, C59, C60, C61: 100n; C_1206_3216Metric_Pad1.33x1.80mm_HandSolder
C16: 22n; C_1210_3225Metric_Pad1.42x2.65mm
C17, C20, C23, C24, C28: C; C_1210_3225Metric_Pad1.42x2.65mm
C31, C35, C37, C54, C55: 1u; C_1206_3216Metric_Pad1.33x1.80mm_HandSolder
C33: 10u; C_1210_3225Metric_Pad1.42x2.65mm
C34: 56u/63V; CP_Elec_8x10
C39, C40, C47: 10n; C_1206_3216Metric_Pad1.33x1.80mm_HandSolder
C51: C; C_1206_3216Metric_Pad1.33x1.80mm_HandSolder
C57: 300u/63V; CP_Elec_10x10
D2, D3, D5: D; D_1206_3216Metric_Pad1.42x1.75mm_HandSolder
D4: LED; LED_0805_2012Metric_Pad1.15x1.40mm_HandSolder
DZ1, DZ2: 5V; D_DO-41_SOD81_P7.62mm_Horizontal_Zener
DZ3, DZ4, DZ5, DZ6: 5V; D_SOD-123F_Zener
FB1, FB2, FB3, FB4, FB5, FB6: FerriteBead; Ferrite_1206_3216Metric_Pad1.42x1.75mm_BigPads
H1, H2, H3, H4, H5, H13: MountingHole_Pad; MountingHole_4.3mm_M4_Pad_TopBottom
H6, H7, H8, H9, H10, H11, H12, H14, H15, H16: MountingHole_Pad; MountingHole_3.2mm_M3_Pad_TopBottom
J1: Conn_Coaxial; SMA_Amphenol_132134_Vertical
J3: Conn_02x20_Counter_Clockwise; PinHeader_2x20_P2.54mm_Vertical
J4: Conn_02x04_Counter_Clockwise; Molex_Micro-Fit_3.0_43045-0812_2x04_P3.00mm_Vertical
J5, J6, J7, J8, J9, J10: Conn_01x02_Pin; TransCoax-povezava
J11: Conn_01x02_Pin; PinHeader_1x02_P2.54mm_Vertical
JP1, JP2, JP3: SolderJumper_2_Open; SolderJumper-2_P1.3mm_Open_Pad1.0x1.5mm
K1: Relay_SPDT-jw1; Relay_SPDT_Panasonic_JW1_FormC
L6: 15turns on 43; choke-amp
L7, L8, L12: L_Ferrite_Small; Ferrite_1206_3216Metric_Pad1.42x1.75mm_BigPads
L9, L11: L_Ferrite; Ferrite_1206_3216Metric_Pad1.42x1.75mm_BigPads
L10: L; Ferrite_1206_3216Metric_Pad1.42x1.75mm_BigPads
Q1: NMOS; MRF300AN
Q2: NMOS; MRF300BN
Q3: Q_NMOS-D_Generic_GDS; TSOT-23_HandSoldering
R7, R8: 100R; R_2512_6332Metric_Pad1.40x3.35mm_HandSolder
R9, R10, R17: 2kR; R_1206_3216Metric_Pad1.42x1.75mm_HandSolder
R11: R; R_1812_4532Metric
R12: 500R; R_1206_3216Metric_Pad1.42x1.75mm_HandSolder
R14: 300R; R_1206_3216Metric_Pad1.42x1.75mm_HandSolder
R15: 5kR; R_1206_3216Metric_Pad1.42x1.75mm_HandSolder
R18: 330R; R_1206_3216Metric_Pad1.30x1.75mm_HandSolder
R19, R20, R21, R22, R23: 1kR; R_1206_3216Metric_Pad1.42x1.75mm_HandSolder
R24: 2k; R_1206_3216Metric_Pad1.30x1.75mm_HandSolder
RV1, RV2: 1kR; Potentiometer_Bourns_3296W_Vertical
RV3: 10k; Potentiometer_Bourns_3296W_Vertical
RV4: 10kR; Potentiometer_Bourns_3296W_Vertical
TP1: BIAS; TestPoint_Pad_D1.5mm
TP2: B2; TestPoint_Pad_D1.5mm
TP3: B1; TestPoint_Pad_D1.5mm
TP5: I; TestPoint_Pad_D1.5mm
U1: MAX40010; SOT-23-6
U2: LM35-LP; TO-220-3_Horizontal_TabDown
U3: LM35-LP; TO-220-3 smd
U4, U5: LM317AT; TO-220-3_Horizontal_TabDown
U6, U7: Opamp_Dual; SSOP-8_2.95x2.8mm_P0.65mm
U8: LM317MKVU; TO-252-2

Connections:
5V-3: C14.1, C25.1, C52.1, FB4.2, J3.16, J3.18, J3.20, J3.22, U1.4 (VDD), U2.1 (+V_{S})
12V-3: J3.24, J3.26, J3.28, L9.2, L11.2
12V-OP: C47.1, C48.1, C49.1, C50.1, C55.2, L11.1, U6.8 (V+), U7.8 (V+), U8.3 (IN)
50V-1: C33.2, C57.1, C58.1, J4.5, J4.6, J4.7, J4.8, L6.2, U1.5 (RS+), U1.6 (RS-)
50V-2: C61.1, J3.30, J3.32, J3.34, J3.36, J3.38, J3.40, L7.1, L12.1
/dov: C16.2, C17.2, C20.2, C23.2, C24.2, C28.2, L6.1
B1: DZ1.1 (K), JP2.1 (A), R7.1, RV1.2, TP3.1
B1buff: C56.1, DZ5.1 (K), J3.2, R21.2
B2: DZ2.1 (K), JP3.1 (A), R8.1, RV2.2, TP2.1
B2buff: C59.1, DZ6.1 (K), J3.8, R22.2
BIAS: L8.2, R9.2, TP1.1
BIAS-OFF: K1.6, R9.1, RV1.1, RV2.1
BIAS-ON: C39.1, D3.2 (A), J3.14
D1: C5.2, C45.2, J5.1, J7.2, J8.1, Q1.1 (D)
D2: C13.2, C46.2, J5.2, J6.1, J7.1, Q2.1 (D)
GNDD: C5.1, C13.1, C14.2, C15.2, C16.1, C17.1, C20.1, C23.1, C24.1, C25.2, C28.1, C29.2, C30.2, C31.2, C32.2, C33.1, C34.2, C35.2, C36.2, C37.2, C38.2, C39.2, C40.2, C41.2, C42.2, C43.2, C44.2, C47.2, C48.2, C49.2, C50.2, C51.1, C52.2, C53.1, C54.1, C55.1, C56.2, C57.2, C58.2, C59.2, C60.2, C61.2, DZ1.2 (A), DZ2.2 (A), DZ3.2 (A), DZ4.2 (A), DZ5.2 (A), DZ6.2 (A), H1.1, H2.1, H3.1, H4.1, H5.1, H6.1, H7.1, H8.1, H9.1, H10.1, H11.1, H12.1, H13.1, H14.1, H15.1, H16.1, J1.2 (Ext), J3.1, J3.3, J3.5, J3.7, J3.9, J3.11, J3.13, J3.15, J3.17, J3.19, J3.21, J3.23, J3.25, J3.27, J3.29, J3.31, J3.33, J3.35, J3.37, J3.39, J4.1, J4.2, J4.3, J4.4, J10.2, J11.2, K1.2, Q1.3 (S), Q2.3 (S), Q3.3 (S), R15.2, R23.1, RV3.1, RV4.1, U1.2 (GND), U2.3 (GND), U3.3 (GND), U6.4 (V-), U7.4 (V-)
I-sense: C51.2, FB3.2, TP5.1, U6.3 (+), U6.5 (+)
Ibuff: C32.1, J3.4, U6.6 (-), U6.7
unnamed: C15.1, FB4.1, FB5.2
unnamed: C30.1, FB2.1, FB6.2
unnamed: C31.1, FB3.1, R18.2
unnamed: D2.2 (A), D4.2 (A), K1.8, Q3.2 (D)
unnamed: C43.1, D3.1 (K), L10.1
unnamed: D4.1 (K), R24.1
unnamed: D5.2 (A), R24.2
unnamed: DZ3.1 (K), R19.2, U7.3 (+)
unnamed: DZ4.1 (K), R20.2, U7.5 (+)
unnamed: J11.1, R10.2
unnamed: C34.1, C35.1, C36.1, JP1.1 (A), L7.2, L12.2, U4.3 (IN)
unnamed: JP1.2 (B), R11.2, U4.1, U5.3 (IN)
unnamed: JP2.2 (B), R19.1
unnamed: JP3.2 (B), R20.1
unnamed: L10.2, R14.1
unnamed: Q3.1 (G), R14.2, R15.1
unnamed: R10.1, RV1.3, RV2.3
unnamed: R12.1, RV3.2, RV3.3, U5.1
unnamed: R17.1, RV4.2, RV4.3, U8.1
unnamed: R18.1, U1.3 (OUT)
unnamed: C29.1, FB1.1, U2.2 (V_{OUT})
unnamed: C44.1, FB5.1, U3.1 (+V_{S})
unnamed: C60.1, FB6.1, U3.2 (V_{OUT})
unnamed: R11.1, U4.2 (OUT)
unnamed: C37.1, C38.1, L8.1, R12.2, U5.2 (OUT)
unnamed: C53.2, C54.2, R17.2, R23.2, U6.2 (-), U8.2 (OUT)
unnamed: R21.1, U7.1, U7.2 (-)
unnamed: R22.1, U7.6 (-), U7.7
PWRRL3: C40.1, C41.1, C42.1, D2.1 (K), D5.1 (K), K1.1, L9.1
T1: FB1.2, J3.12
T2: FB2.2, J3.10
izh: J1.1 (In), J10.1
izh1: C1.1, C2.1, C3.1, C6.1, J6.2
izh1po: C1.2, C2.2, C3.2, C6.2, J9.1
izh2: C7.1, C9.1, C10.1, C11.1, J8.2
izh2po: C7.2, C9.2, C10.2, C11.2, J9.2
overcurrent: J3.6, U6.1

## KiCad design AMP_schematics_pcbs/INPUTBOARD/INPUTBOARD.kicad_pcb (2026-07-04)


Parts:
C1: 1000u; CP_Radial_D12.5mm_P5.00mm
C2: 470u; CP_Radial_D16.0mm_P7.50mm
C3, C10, C19, C20, C24, C28: 1u; C_1206_3216Metric_Pad1.33x1.80mm_HandSolder
C4, C5, C11, C13, C18, C21, C22, C23, C25, C26, C27, C29, C31, C32: 100n; C_1206_3216Metric_Pad1.33x1.80mm_HandSolder
C6, C30, C33: 10n; C_1206_3216Metric_Pad1.33x1.80mm_HandSolder
C7: 100n; C_1206_3216Metric_Pad1.33x1.80mm_HandSolder; not fitted
C8: 100u; CP_EIA-7343-30_AVX-N_HandSolder
C9: 100u; CP_EIA-7343-30_AVX-N_HandSolder; not fitted
C14, C16: C; CP_Radial_D10.0mm_P5.00mm; not fitted
C15: 470u; CP_Radial_D10.0mm_P5.00mm
C17: 330u; CP_Elec_8x10
D1, D2, D4, D5: D; D_1206_3216Metric_Pad1.42x1.75mm_HandSolder
D3: 1n5711; D_DO-35_SOD27_P7.62mm_Horizontal
D6: LED; LED_0805_2012Metric_Pad1.15x1.40mm_HandSolder
DZ1: 10V; D_DO-35_SOD27_P7.62mm_Horizontal
FB1: Ferrite_Bead; Ferrite_1206_3216Metric_Pad1.22x1.90mm_BigPads
H1, H2, H3, H4, H5: MountingHole_Pad; MountingHole_3.5mm_Pad
J1, J5: Conn_Coaxial; SMA_Amphenol_132134_Vertical
J2: Conn_01x05_Pin; plosca-frek
J3, J4: Conn_02x04_Counter_Clockwise; Molex_Micro-Fit_3.0_43045-0812_2x04_P3.00mm_Vertical
J6: Conn_02x10_Counter_Clockwise; PinHeader_1x20_P1.27mm_Vertical
J7, J8: Conn_02x02_Odd_Even; Molex_Micro-Fit_3.0_43045-0412_2x02_P3.00mm_Vertical
K1, K2: Relay_SPDT-jw1; relej-izhodni
K3, K4: Relay_SPDT-jw1; relej-prozoren16A
L1, L7, L8: L; Ferrite_1206_3216Metric_Pad1.42x1.75mm_BigPads
L2: 2t; Ferrite_1206_3216Metric_Pad1.42x1.75mm_BigPads
L3, L4, L5, L6: L_Ferrite_Small; Ferrite_1206_3216Metric_Pad1.22x1.90mm_BigPads
OC1: 4N25M; DIP-6_W7.62mm_LongPads
Q1, Q3: IRLML6244; SOT-23_Handsoldering
Q2: 2N2907; TO-18-3_EBC
R1: 300R; R_1206_3216Metric_Pad1.30x1.75mm_HandSolder
R2, R17, R18: 5kR; R_1206_3216Metric_Pad1.30x1.75mm_HandSolder
R3: NC; R_1206_3216Metric
R4, R9, R12, R15: 10k; R_1206_3216Metric_Pad1.30x1.75mm_HandSolder
R5, R16: 5k; R_1206_3216Metric_Pad1.30x1.75mm_HandSolder
R6: 330R; R_1206_3216Metric_Pad1.30x1.75mm_HandSolder
R7: 100k; R_1206_3216Metric_Pad1.30x1.75mm_HandSolder
R8: 1M; R_1206_3216Metric_Pad1.30x1.75mm_HandSolder
R10: 560k; R_1206_3216Metric_Pad1.30x1.75mm_HandSolder
R11: 22k; R_1206_3216Metric_Pad1.30x1.75mm_HandSolder
R13: 1k; R_1206_3216Metric_Pad1.30x1.75mm_HandSolder
R14: 100R; R_1206_3216Metric_Pad1.30x1.75mm_HandSolder
U1: AMS1117-5.0; SOT-223-3_TabPin2

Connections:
5V-freqb: C9.1, C10.1, J2.3, J2.4, U1.2 (VO)
12V-5: C8.1, C17.1, C18.1, C19.1, J6.6, J6.8, J6.10, J6.12, J6.14, J6.16, L3.1, L4.1, U1.3 (VI)
12V-REL1: C3.1, C26.1, C27.1, C28.1, C31.1, D4.1 (K), D6.2 (A), K1.8, K2.8, L6.2, Q2.1 (E), R9.1
12V-REL2: C23.1, C24.1, C25.1, D1.1 (K), K3.8, K4.8, L5.2
50V-IN: C1.1, C2.1, J3.5, J3.6, J3.7, J3.8, K3.4, K4.4
50V-OUT: J4.5, J4.6, J4.7, J4.8, K3.6, K4.6
/rfin-po: K2.6
/t1: L2.2, R5.1
/t2: L2.1, R4.2
AMPizhod: J1.1 (In), K1.4
AMPvhod: J5.1 (In), K2.4
FREQ-B: J2.5, J6.2
GNDD: C1.2, C2.2, C3.2, C4.2, C5.2, C6.2, C7.2, C8.2, C9.2, C10.2, C11.2, C13.2, C14.2, C15.2, C16.2, C17.2, C18.2, C19.2, C20.2, C21.2, C22.2, C23.2, C24.2, C25.2, C26.2, C27.2, C28.2, C29.2, C30.2, C31.2, C32.2, C33.2, DZ1.2 (A), H1.1, H2.1, H3.1, H4.1, H5.1, J1.2 (Ext), J2.1, J2.2, J3.1, J3.2, J3.3, J3.4, J4.1, J4.2, J4.3, J4.4, J5.2 (Ext), J6.1, J6.3, J6.5, J6.7, J6.9, J6.11, J6.13, J6.15, J6.17, J6.19, J7.3, J7.4, J8.3, J8.4, OC1.2, OC1.4, Q1.2 (S), Q3.2 (S), R2.2, R3.1, R4.1, R8.2, R11.2, R15.1, R16.2, R17.2, U1.1 (GND)
unnamed: C6.1, L1.2, R1.1
unnamed: C11.1, R7.2, R8.1
unnamed: C20.1, C21.1, C22.1, L3.2, L4.2, L5.1, L6.1
unnamed: C30.1, L7.2, R10.2, R15.2
unnamed: C33.1, L8.2, R14.1
unnamed: C5.1, D2.1 (K), L1.1
unnamed: D3.2 (A), R5.2
unnamed: D3.1 (K), R6.1, R7.1
unnamed: D5.2 (A), Q2.3 (C), R16.1
unnamed: D5.1 (K), R13.1
unnamed: D6.1 (K), R18.1
unnamed: C32.1, DZ1.1 (K), L8.1, R13.2
unnamed: FB1.1, R6.2
unnamed: C14.1, C15.1, C16.1, J7.1, J7.2, J8.1, J8.2
unnamed: K1.2, K2.2
unnamed: OC1.1, R10.1
unnamed: OC1.5, R12.2
unnamed: OC1.6, R11.1
unnamed: Q1.1 (G), R1.2, R2.1
unnamed: Q2.2 (B), R9.2, R12.1
unnamed: Q3.1 (G), R14.2, R17.1
PWR50ON: C4.1, D2.2 (A), J6.20
REL1: D4.2 (A), K1.1, K2.1, Q3.3 (D), R18.2
REL2: D1.2 (A), K3.1, K4.1, Q1.3 (D)
RF-IN: R3.2
RF-OUT: K1.6
RFD-B: C7.1, FB1.2, J6.4
TX-ON: C13.1, C29.1, J6.18, L7.1

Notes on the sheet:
relays TX/RX
diode rf detection
5v logic mosfet
capacitors 50V
5V supply for fd
rf relay on
relays 50V
supply filters
connectors
50V relay on



Board: 2 copper layers, 250.0 x 40.0 mm, 87 parts (18 on the bottom side), 36 nets.

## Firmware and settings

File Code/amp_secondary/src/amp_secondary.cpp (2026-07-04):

// ================= AMP SECONDARY MCU =================
// Responsibilities:
//   - Read all temperatures (LM35DT on A10, A11, A12)
//   - Read all voltages (5V and 12V rails for 3 boards, 18V, 50V)
//   - Read current on 18V and 50V rails
//   - Report temps and voltage fault flag to main MCU via UART
//   - Drive Nextion HMI display (Serial2)
//   - Drive 6x PWM fans based on heatsink temperature
//   - Forward operator reset from HMI to main MCU, with temperature gate
//   - INIT grace period: skip fault reporting for first INIT_GRACE_MS

// =====================================================================
// SERIAL1 RX BUFFER SIZE REQUIREMENT
// =====================================================================
// The Nextion HMI library blocks for ~15ms per setText/setValue call while
// waiting for an ACK at 9600 baud. During that window, the main MCU is
// streaming telemetry on Serial1 at 115200 baud (~11.5 kB/s). The default
// 64-byte hardware buffer will overflow (~173 bytes arrive in 15ms),
// causing UART CRC errors and eventually commFault latching.
//
// To prevent this, the Serial1 RX buffer must be bumped to 256 bytes.
//
//   PlatformIO:  add to platformio.ini:
//                  build_flags = -DSERIAL_RX_BUFFER_SIZE=256
//
//   Arduino IDE: easiest is to add this line to platform.local.txt:
//                  compiler.cpp.extra_flags=-DSERIAL_RX_BUFFER_SIZE=256
//                (or edit HardwareSerial.h directly)
//
// The line below MAY work if the Arduino core hasn't already included
// HardwareSerial.h before reaching this point — but the build flag above
// is the reliable method. Keep both for safety.
// #define SERIAL_RX_BUFFER_SIZE 256
// =====================================================================
#include "Arduino.h"
#include "UART.h"
#include "Nextion.h"

#include <Arduino.h>
#include "UART.h"
#include "Nextion.h"

// ================= FORWARD DECLARATIONS =================

// Fan PWM
void     fan_pwm_init();
void     setFanPWM(uint8_t duty);
void     updateFans(float heatsinkTemp);

// Sensors
void readTemperatures();
void readVoltages();
bool checkVoltageFaults();
void reportSensors();

// Display
void updateNextionDisplay();
const char* getStateString(uint8_t state);
const char* getFaultString(uint8_t code);
const char* getBandString(uint8_t band);

// UART
void secondaryUARTHandler(uint8_t type, uint16_t value);

// Nextion callbacks
void p1b0PopCallback(void *ptr);
void p1b1PopCallback(void *ptr);

// ================= END FORWARD DECLARATIONS =================

#define DEBUG_SERIAL
// ================= TEMP ENABLE FLAGS =================
#define ENABLE_TEMP_HEATSINK      // A11 — LM35DT on MRF300 TO-247 case
//#define ENABLE_TEMP_INNER       // A12 — LM35DT inner board (currently NC)
//#define ENABLE_TEMP_AIR         // A10 — LM35DT ambient air (currently NC)

// ================= PIN DEFINITIONS =================

#define PinTempInner          A12
#define PinTempHeatsink       A10
#define PinTempAir            A11

#define IsenseEighteenV       A9
#define IsenseFiftyV          A8

#define VsenseFiveVboardTwo   A7
#define VsenseTwelveVboardTwo A6
#define VsenseFiveVboardThree A5
#define VsenseTwelveVboardThree A4
#define VsenseFiveVboardOne   A3
#define VsenseTwelveVboardOne A2
#define VsenseEighteenV       A1
#define VsenseFiftyV          A0

#define rffrequency  2
#define PinFan1     44
#define PinFan2     45
#define PinFan3     46
#define PinFan4     12
#define PinFan5     11
#define PinFan6     10
#define buzzer      49

// ================= UART PACKET TYPES =================
// Types 0x00–0x7F: main MCU sends, secondary receives
// Types 0x80–0xFF: secondary MCU sends, main receives

// Inbound from main MCU (secondary receives these)
#define TYPE_FAULT_REASON    0x10
#define TYPE_AMP_STATE       0x20
#define TYPE_OUT_POWER       0x21   // output forward power W×10
#define TYPE_OUT_SWR         0x22   // output SWR ×100
#define TYPE_IN_POWER        0x23   // input forward power W×10
#define TYPE_IN_SWR          0x24   // input SWR ×100
#define TYPE_AMP_CURRENT     0x25   // amp supply current in mA
#define TYPE_GAIN            0x26   // gain dB×10 offset +500
#define TYPE_EFFICIENCY      0x27   // efficiency integer percent 0–100
#define TYPE_BAND            0x28   // set band 1–5, 0=none
#define TYPE_SSB_MODE        0x74   // HMI SSB button — bidirectional toggle/state

// Outbound to main MCU (secondary sends these)
#define TYPE_TEMP_HEATSINK   0x80
#define TYPE_TEMP_INNER      0x81
#define TYPE_TEMP_AIR        0x82
#define TYPE_VOLTAGE_FAULT   0x83

// Protocol types (bidirectional)
#define TYPE_RESET           0x72

// ================= FAULT REASON CODES =================
// Mirror of main MCU FaultReason_t — used to decide temperature reset gate
#define FAULT_NONE           0
#define FAULT_TEMP_HIGH      50
#define FAULT_TEMP_CRITICAL  51

// ================= VOLTAGE THRESHOLDS =================

#define VOLT_5V_LOW    4.5f
#define VOLT_5V_HIGH   8.5f
#define VOLT_12V_LOW  10.8f
#define VOLT_12V_HIGH 13.2f
#define VOLT_18V_LOW  15.0f
#define VOLT_18V_HIGH 20.0f
#define VOLT_50V_LOW  44.0f
#define VOLT_50V_HIGH 56.0f

// ================= ADC SCALING =================

#define ADC_VREF            5.0f
#define ADC_STEPS        1024.0f
#define ADC_LSB          (ADC_VREF / ADC_STEPS)
#define SCALE_DIVIDED_RAIL (ADC_LSB * 4.4f)   // ÷4 divider on 5V/12V rails
#define SCALE_DIVIDED_RAIL_FIVE (ADC_LSB * 2.0f)
#define SCALE_18V          0.0294f              
#define SCALE_50V          0.079f              
#define SCALE_I18V         0.008f               
#define SCALE_I50V         0.037f               

// LM35DT: 10mV/°C, Vref=5V → 0.4883°C per LSB
#define SCALE_LM35  (ADC_VREF * 1000.0f / ADC_STEPS / 10.0f)

// ================= TEMPERATURE THRESHOLDS =================

#define TEMP_HEATSINK_RESET  60.0f   // must be below this to permit reset after FAULT_TEMP_HIGH

// ================= TEMPERATURE SLEW RATE =================
// Limits how fast the heatsink reading can rise, to reject RF-induced
// voltage spikes on the LM35DT sense line (e.g. sudden false 100°C reads).
// Fall rate is unrestricted — real cooling must be tracked immediately.
// Rate: 1°C per 500ms. Interval is SENSOR_INTERVAL_MS (50ms).
// → Max rise per read = 0.1°C
#define TEMP_MAX_RISE_PER_READ  (1.0f * SENSOR_INTERVAL_MS / 500.0f)

static float tempHeatsinkFiltered = 0.0f;
static bool  tempHeatsinkInitDone = false;

// ================= FAN CONTROL =================

// Fan curve — heatsink case temperature drives all 6 fans together.
// Below FAN_TEMP_ON: fans off.
// At FAN_TEMP_ON: hard jump to FAN_PWM_MIN (30%) to guarantee start.
// FAN_TEMP_ON to FAN_TEMP_MAX: linear ramp FAN_PWM_MIN → 255.
// Above FAN_TEMP_MAX: locked at 255 (100%).

#define FAN_TEMP_ON          35.0f   // °C — turn fans on (rising edge)
#define FAN_TEMP_HYSTERESIS   3.0f   // °C — turn-off threshold is FAN_TEMP_ON - this
#define FAN_TEMP_OFF         (FAN_TEMP_ON - FAN_TEMP_HYSTERESIS)  // °C — turn fans off (falling edge)
#define FAN_TEMP_MAX         70.0f   // °C — fans at 100% (also soft fault threshold on main MCU)
#define FAN_PWM_MIN             77   // 30% of 255 — minimum to guarantee spin-up

static uint8_t fanPWM = 0;    // current fan duty cycle 0–255, tracked for display


#define FAN_PWM_TOP_16BIT 799   // Timer1/Timer5 TOP for 20kHz at 16MHz

void fan_pwm_init() {
  // --- Timer1: D11 (Fan5, OC1A), D12 (Fan4, OC1B) ---
  // COM1A1=1, COM1B1=1: non-inverting (clear on match, set at BOTTOM)
  // WGM13:0 = 1110 → mode 14 (Fast PWM, TOP=ICR1)
  // CS12:0 = 001 → prescaler 1
  TCCR1A = (1 << COM1A1) | (1 << COM1B1) | (1 << WGM11);
  TCCR1B = (1 << WGM13)  | (1 << WGM12)  | (1 << CS10);
  ICR1   = FAN_PWM_TOP_16BIT;
  OCR1A  = 0;  // Fan5 off
  OCR1B  = 0;  // Fan4 off

  // --- Timer5: D44 (Fan1, OC5C), D45 (Fan2, OC5B), D46 (Fan3, OC5A) ---
  TCCR5A = (1 << COM5A1) | (1 << COM5B1) | (1 << COM5C1) | (1 << WGM51);
  TCCR5B = (1 << WGM53)  | (1 << WGM52)  | (1 << CS50);
  ICR5   = FAN_PWM_TOP_16BIT;
  OCR5A  = 0;  // Fan3 off
  OCR5B  = 0;  // Fan2 off
  OCR5C  = 0;  // Fan1 off

  // --- Timer2: D10 (Fan6, OC2A) ---
  // COM2A1=1: non-inverting
  // WGM22:0 = 001 → mode 1 (Phase-correct PWM, TOP=0xFF)
  // CS22:0 = 001 → prescaler 1
  TCCR2A = (1 << COM2A1) | (1 << WGM20);
  TCCR2B = (1 << CS20);
  OCR2A  = 0;  // Fan6 off
}

// Apply 0..255 duty cycle to all fans. Internally scales the value to
// the appropriate range for each timer. Intentionally keeps the same
// 0..255 API as the original analogWrite()-based code so updateFans()
// doesn't need to change its internal math.

void setFanPWM(uint8_t duty) {
  // Timer1 / Timer5 use 0..(TOP+1) for 0..100% duty.
  // Scale 0..255 → 0..800. At duty=0 → 0 (always low),
  // at duty=255 → 800 (always high, since 800 > TOP).
  uint16_t duty16 = (uint16_t)(((uint32_t)duty * (FAN_PWM_TOP_16BIT + 1)) / 255UL);

  OCR1A = duty16;  // Fan5
  OCR1B = duty16;  // Fan4
  OCR5A = duty16;  // Fan3
  OCR5B = duty16;  // Fan2
  OCR5C = duty16;  // Fan1

  OCR2A = duty;    // Fan6 — native 8-bit range, no scaling
}

void updateFans(float heatsinkTemp) {
  uint8_t pwm;

  // Use current fan state to decide which threshold applies.
  // fansOn==true  → use lower threshold FAN_TEMP_OFF before shutting down
  // fansOn==false → require full FAN_TEMP_ON before starting up
  bool fansOn = (fanPWM > 0);
  float lowerThreshold = fansOn ? FAN_TEMP_OFF : FAN_TEMP_ON;

  if (heatsinkTemp < lowerThreshold) {
    // Below the active threshold — fans off (or stay off).
    pwm = 0;
  } else if (heatsinkTemp >= FAN_TEMP_MAX) {
    // Above max — full speed.
    pwm = 255;
  } else if (heatsinkTemp < FAN_TEMP_ON) {
    // In the hysteresis band AND fans are already on
    // (else we'd have taken the first branch). Hold at minimum to
    // keep them reliably spinning without dropping below stall PWM.
    pwm = FAN_PWM_MIN;
  } else {
    // Normal linear ramp from FAN_PWM_MIN at FAN_TEMP_ON up to 255 at FAN_TEMP_MAX.
    float fraction = (heatsinkTemp - FAN_TEMP_ON) / (FAN_TEMP_MAX - FAN_TEMP_ON);
    pwm = (uint8_t)(FAN_PWM_MIN + fraction * (255 - FAN_PWM_MIN));
  }

  if (pwm != fanPWM) {
    fanPWM = pwm;
    setFanPWM(pwm);
  }
}


// ================= TIMING =================

#define INIT_GRACE_MS      1500UL
#define SENSOR_INTERVAL_MS   50UL
#define REPORT_INTERVAL_MS  100UL

// ================= UART RANGE TABLE =================
// Inbound from main MCU — all types that secondary expects to receive

Range secondaryRanges[] = {
  {TYPE_FAULT_REASON, 0,  99},
  {TYPE_AMP_STATE,    0,  12},   // was 11 — now includes AMP_SSB_VERIFY
  {TYPE_SSB_MODE,     0,   1},   // new — main MCU echoes 0/1 state back
  {TYPE_OUT_POWER,    0, 9999},
  {TYPE_OUT_SWR,      0, 9999},
  {TYPE_IN_POWER,     0, 9999},
  {TYPE_IN_SWR,       0, 9999},
  {TYPE_AMP_CURRENT,  0, 25000},
  {TYPE_GAIN,         0, 9999},
  {TYPE_EFFICIENCY,   0,  100},
  {TYPE_BAND,         0,    5}
};

// ================= DISPLAY RECEIVED VALUES =================
// Stored here as received from main MCU, decoded for display

static uint8_t  dispAmpState   = 0;
static uint16_t dispOutPower   = 0;    // W×10
static uint16_t dispOutSWR     = 100;  // SWR×100 (1.00 default)
static uint16_t dispInPower    = 0;
static uint16_t dispInSWR      = 100;
static uint16_t dispAmpCurrent = 0;    // mA
static uint16_t dispGain       = 500;  // dB×10 offset +500 (0dB default)
static uint8_t  dispEfficiency = 0;
static uint8_t  dispBand       = 0;
static uint8_t  dispFaultReason = FAULT_NONE;

// ================= SENSOR VALUES =================

int tempHeatsink = 0;
int tempInner    = 0;
int tempAir      = 0;

float volt5V_board1  = 0.0f;
float volt12V_board1 = 0.0f;
float volt5V_board2  = 0.0f;
float volt12V_board2 = 0.0f;
float volt5V_board3  = 0.0f;
float volt12V_board3 = 0.0f;
float volt18V        = 0.0f;
float volt50V        = 0.0f;
float curr18V        = 0.0f;
float curr50V        = 0.0f;

bool voltageFault = false;

// Grace period flag — voltage faults suppressed until supply rails have settled
static bool          gracePeriodDone = false;
static unsigned long initStartTime   = 0;

// ================= NEXTION HMI =================

NexProgressBar p1j0 = NexProgressBar(1,  9, "j0");  // output power bar 0–550W
NexProgressBar p1j1 = NexProgressBar(1, 10, "j1");  // output SWR bar 1.00–3.00

NexButton      p1b0 = NexButton(1, 11, "b0");       // RESET SOFT FAULT
NexButton      p1b1 = NexButton(1, 27, "b1");       // SSB MODE toggle button


NexText        p1t0  = NexText(1, 12, "t0");         // fault description string
NexText        p1t9  = NexText(1, 21, "t9");         // amp state string
NexText        p1t14 = NexText(1, 26, "t14");        // band string
NexText        p1t15 = NexText(1,  28, "t15");       // SSB mode status indicator

NexNumber      p1n0 = NexNumber(1, 1, "n0");         // output forward power (W)
NexNumber      p1n1 = NexNumber(1, 2, "n1");         // output SWR ×100
NexNumber      p1n2 = NexNumber(1, 3, "n2");         // input forward power (W)
NexNumber      p1n3 = NexNumber(1, 4, "n3");         // input SWR ×100
NexNumber      p1n4 = NexNumber(1, 5, "n4");         // amp supply current (mA)
NexNumber      p1n5 = NexNumber(1, 6, "n5");         // heatsink temperature (integer °C)
NexNumber      p1n6 = NexNumber(1, 7, "n6");         // gain (dB, decoded)
NexNumber      p1n7 = NexNumber(1, 8, "n7");         // power loss (100 - efficiency %)

NexTouch *nex_listen_list[] = {
  &p1b0,
  &p1b1,   
  NULL
};

static bool hmiResetButton = false;
static bool dispSSBMode  = false;
static bool hmiSSBButton = false;

void p1b0PopCallback(void *ptr) {
  hmiResetButton = true;
}

void p1b1PopCallback(void *ptr) {
  hmiSSBButton = true;
}

// ================= AMP STATE NAME LOOKUP =================

const char* getStateString(uint8_t state) {
  switch (state) {
    case  0: return "IZKLOPLJEN";
    case  1: return "INIT";
    case  2: return "MIROVANJE";
    case  3: return "ZAGON";
    case  4: return "NASTAV. VHODA";
    case  5: return "NIZKA ODDAJA";
    case  6: return "UGLASITEV";
    case  7: return "PREHOD";
    case  8: return "ODDAJANJE";
    case  9: return "PRIPRAVLJEN";
    case 10: return "SSB VER";
    case 11: return "MEHKA NAPAKA";
    case 12: return "NAPAKA";
    default: return "NEZNANO";
  }
}
/*
    case  0: return "IZKLOPLJEN";
    case  1: return "INIT";
    case  2: return "MIROVANJE";
    case  3: return "ZAGON";
    case  4: return "NASTAV. VHODA";
    case  5: return "NIZKA ODDAJA";
    case  6: return "UGLASITEV";
    case  7: return "PREHOD";
    case  8: return "ODDAJANJE";
    case  9: return "PRIPRAVLJEN";
    case 10: return "SSB VER";
    case 11: return "MEHKA NAPAKA";
    case 12: return "NAPAKA";
    default: return "NEZNANO";
*/
/*
    case  0: return "OFF";
    case  1: return "INIT";
    case  2: return "IDLE";
    case  3: return "STARTUP";
    case  4: return "ADJUST INPUT";
    case  5: return "LOW TRANSMIT";
    case  6: return "TUNE";
    case  7: return "TRANSITION";
    case  8: return "TRANSMIT";
    case  9: return "READY";
    case 10: return "SSB VERIFY";   
    case 11: return "SOFT FAULT";   
    case 12: return "FAULT";        
    default: return "UNKNOWN";
*/



// ================= FAULT REASON NAME LOOKUP =================

const char* getFaultString(uint8_t code) {
  switch (code) {
    case  0: return "BREZ NAPAKE";
    case  1: return "NAPAKA OJ.";
    case  2: return "RF NEVELJAVEN";
    case  3: return "BAND NEVELJAVEN";
    case  4: return "BAND NESTABILEN";
    case  5: return "NASTAV. BAND";
    case  6: return "SPREMEMBA BAND";
    case  7: return "UART KOMM";
    case  8: return "ADC HRDWR";
    case  9: return "SENZOR TOKA";
    case 10: return "ZAGON BIAS";
    case 20: return "TUNE. NESTAB.";
    case 21: return "VHOD PREVISOK";
    case 22: return "ATT PREVERJANJE";
    case 23: return "ATT BREZ ZMANJ.";
    case 24: return "RF IZGUBLJEN";
    case 30: return "VHOD PREOBREMEN";
    case 33: return "VHOD VISOK CAKAJ";
    case 40: return "VISOK SWR";
    case 41: return "NIZKO OJACENJE";
    case 42: return "NIZ. IZKORISTEK";
    case 43: return "MIROVALNI TOK";
    case 44: return "SR LATCH";
    case 45: return "VISOK SWR2";
    case 50: return "PREVISOKA TEMP.";
    case 51: return "KRITICNA TEMP.";
    case 60: return "NIZKA NAPETOST";
    case 61: return "VISOK TOK";
    case 62: return "GATE DRIFT";
    case 63: return "50V NI PRISOTEN";
    case 64: return "50V OSTAJA";
    case 65: return "VHODNI SWR VIS.";
    case 98: return "POKVARJ. STANJE";
    case 99: return "NUJNI IZKLOP";
    default: return "NEZNANA NAPAKA";
  }
}
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
void loop() {
  // --- UART housekeeping ---
  UART_readSerial();
  UART_parse();
  UART_sendHeartbeat();
  UART_checkHeartbeat();
  UART_sendBootID();
  UART_updateFaults();

  // --- Nextion event polling ---
  nexLoop(nex_listen_list);

  // --- Reset button handling ---
  // Temperature gate: silently ignore reset if heatsink is above cooling threshold.
  // The fault display already shows OVERTEMPERATURE — the operator knows why.
  if (hmiResetButton) {
    hmiResetButton = false;

    bool isTempFault = (dispFaultReason == FAULT_TEMP_HIGH ||
                        dispFaultReason == FAULT_TEMP_CRITICAL);

    if (!isTempFault || tempHeatsink < TEMP_HEATSINK_RESET) {
      UART_send(TYPE_RESET, 0);
    }
  }
  
  if (hmiSSBButton) {
    hmiSSBButton = false;
    UART_send(TYPE_SSB_MODE, 0);   // value ignored — main MCU owns toggle state
  }

  // --- Timed sensor read ---
  static unsigned long lastSensorRead = 0;
  unsigned long now = millis();

  if (now - lastSensorRead >= SENSOR_INTERVAL_MS) {
    lastSensorRead = now;
    readTemperatures();
    readVoltages();
    updateFans(tempHeatsink);
  }

  // --- Grace period / voltage fault ---
  // Suppress voltage faults for the first INIT_GRACE_MS after boot
  // (supply rails may be low during capacitor inrush at startup)
  if (!gracePeriodDone && (now - initStartTime >= INIT_GRACE_MS)) {
    gracePeriodDone = true;
    Serial2.write(0xFF);
    Serial2.write(0xFF);
    Serial2.write(0xFF);
    Serial2.print("page page1");
    Serial2.write(0xFF);
    Serial2.write(0xFF);
    Serial2.write(0xFF);
    delay(5);
  }
  voltageFault = gracePeriodDone && checkVoltageFaults();

  // --- Timed UART report ---
  static unsigned long lastReport = 0;
  if (now - lastReport >= REPORT_INTERVAL_MS) {
    lastReport = now;
    reportSensors();
  }

  // --- Nextion display update ---
  // Only writes to display when something has changed (nexDirty flag)
  if(gracePeriodDone) updateNextionDisplay();

  // --- Debug output ---
#ifdef DEBUG_SERIAL
  static unsigned long lastDebug = 0;
  if (now - lastDebug >= 500) {
    lastDebug = now;

    Serial.print("Grace done: "); Serial.println(gracePeriodDone ? "YES" : "no");

    Serial.print("Heatsink: "); Serial.print(tempHeatsink);
    Serial.print("C | Inner: "); Serial.print(tempInner);
    Serial.print("C | Air: ");   Serial.print(tempAir); Serial.println("C");

    Serial.print("Fan PWM: "); Serial.print(fanPWM);
    Serial.print(" ("); Serial.print((fanPWM * 100) / 255); Serial.println("%)");

    Serial.print("5V  B1: ");  Serial.print(volt5V_board1,  2);
    Serial.print("  B2: ");    Serial.print(volt5V_board2,  2);
    Serial.print("  B3: ");    Serial.println(volt5V_board3, 2);

    Serial.print("12V B1: ");  Serial.print(volt12V_board1, 2);
    Serial.print("  B2: ");    Serial.print(volt12V_board2, 2);
    Serial.print("  B3: ");    Serial.println(volt12V_board3, 2);

    Serial.print("18V: ");     Serial.print(volt18V, 2);
    Serial.print("V  50V: ");  Serial.print(volt50V, 2); Serial.println("V");

    Serial.print("I18V: ");    Serial.print(curr18V, 2);
    Serial.print("A  I50V: "); Serial.print(curr50V, 2); Serial.println("A");

    Serial.print("VoltageFault: "); Serial.println(voltageFault ? "YES" : "no");

    Serial.print("AmpState: ");     Serial.print(dispAmpState);
    Serial.print(" | FaultReason: "); Serial.println(dispFaultReason);

    Serial.print("OutPwr: ");  Serial.print(dispOutPower  / 10);
    Serial.print("W  OutSWR: "); Serial.print(dispOutSWR, DEC);
    Serial.print("  InPwr: ");   Serial.print(dispInPower / 10);
    Serial.print("W  InSWR: "); Serial.println(dispInSWR, DEC);

    Serial.print("Gain: ");    Serial.print(((int16_t)dispGain - 500) / 10);
    Serial.print("dB  Eff: "); Serial.print(dispEfficiency);
    Serial.print("%  Loss: "); Serial.print(100 - dispEfficiency);
    Serial.print("%  Iamp: "); Serial.print(dispAmpCurrent); Serial.println("mA");

    Serial.print("Band: ");    Serial.println(dispBand);

    Serial.print("UART Errors: "); Serial.print(UART_errorCount());
    Serial.print("  CommFault: "); Serial.print(UART_commFault());
    Serial.print("  HBFault: ");   Serial.println(UART_heartbeatFault());

    Serial.print("SSB Mode: "); Serial.println(dispSSBMode ? "ON" : "off");

    Serial.println("---");
  }
#endif
}

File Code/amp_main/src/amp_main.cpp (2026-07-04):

// ================= AMP MAIN =================
#include "Arduino.h"
#include <Wire.h>
#include <math.h>
#include "UART.h"
#include "ADC.h"
#include <avr/pgmspace.h>

// ================= FORWARD DECLARATIONS =================
// Predeclare all functions in this file so definition order doesn't matter.

typedef enum {
  INPUT_PWR_LOW  = 0,   // ~1.5W — AMP_LOW_TRANSMIT
  INPUT_PWR_MED  = 1,   // ~3.0W — high-gain bands
  INPUT_PWR_HIGH = 2    // ~5.0W — lower-gain bands
} InputPowerTarget_t;

InputPowerTarget_t getBandPowerTarget(uint8_t band);

// Safe state / hardware reset
void setSafeState();
void tunerDefaultOffState();
void attenuatorReset();
void LPFreset();
void AMP_pin_init();

// RF detection
void rfDetectorUpdate();
bool rfPresent();
bool rfOnDelayReached();
bool rfSignalDelayReached();
bool rfSignalValid();
bool rfSignalStable();
bool rfSignalNotValidTimeout();
bool rfSignalOutOfRangeCheck();

// Frequency / band
void freqDetector();
int  getFrequencyBand();
bool bandStable(uint8_t band);
bool setBand(uint8_t band);

// Protection
bool checkProtectionFast();
bool checkProtectionSlow();
void resetProtectionSlow();
bool checkSRLatch();
bool checkOutputSWR(uint8_t &sustainedCount);
bool checkInputSWR(uint8_t &sustainedCount);
void checkAllFaults();

// Performance
float getAmpCurrent();
float computeGain();
float computeDCInputPower();
float computeEfficiency();
bool checkAmpPerformance(bool &hardFault, InputPowerTarget_t target = INPUT_PWR_LOW);

// SWR
float SWR(float Pf, float Pr);
float SWR_input();
float SWR_output();

// Attenuator / tuning
float   maskToDb(uint8_t mask);
uint8_t getAttMaskFromTable(float inputPower, InputPowerTarget_t target);
bool    powerOutOfRange(float measured, float expected);
float   expectedOutputPower(float Pin, float att_db);
void    applyAttenuatorMask(uint8_t mask);
bool    getAveragedInputPowerNB(float &result);
bool    inputPowerStable(float p);
void    resetInputPowerStable();
bool    inputPowerTooHigh(float p, InputPowerTarget_t target);
bool    inputPowerTooHighWait(float p, InputPowerTarget_t target);
bool    runInputTuning(InputPowerTarget_t target);

// State machine
void updateAmpState();

// UART / telemetry
void sendTelemetry();
void myUARTHandler(uint8_t type, uint16_t value);
void IVcheck();
void emergencyInputPowerShutdown();

// ================= END FORWARD DECLARATIONS =================

// ================= AMP STATE MACHINE =================

typedef enum {
  AMP_OFF = 0,
  AMP_INIT,
  AMP_IDLE,
  AMP_FIRST_STARTUP,
  AMP_FIRST_ADJUST_INPUT,
  AMP_LOW_TRANSMIT,
  AMP_TUNE,
  AMP_TRANSMIT_TRANSITION,
  AMP_TRANSMIT_HIGH,
  AMP_READY,
  AMP_SSB_VERIFY,
  AMP_SOFT_FAULT,
  AMP_FAULT
} AmpState_t;

/*
  AMP_OFF               — wait state (startup grace cycles)
  AMP_INIT              — first init, hardware reset to safe state
  AMP_IDLE              — amp idle, waiting for RF
  AMP_FIRST_STARTUP     — RF detected, begin transmit procedure
  AMP_FIRST_ADJUST_INPUT— adjusting and confirming input power via attenuator
  AMP_LOW_TRANSMIT      — transmitting at low output power
  AMP_TUNE              — tuning output impedance matching network (placeholder)
  AMP_TRANSMIT_TRANSITION — changing input power for high output
  AMP_TRANSMIT_HIGH     — transmitting at high output power
  AMP_READY             — configuration set, waiting for next TX
  AMP_SOFT_FAULT        — latched fault, cleared only by UI MCU reset command
  AMP_FAULT             — hard fault, requires power cycle
*/

// Named fault reasons — sent to UI MCU via UART on every fault
typedef enum {
  FAULT_NONE                = 0,
  FAULT_AMPLIFIER           = 1,   // hardware hard fault (generic)
  FAULT_RF_SIGNAL_INVALID   = 2,   // signal must be valid for signalNotValidCountdown
  FAULT_BAND_INVALID        = 3,   // freq. is out of specified band
  FAULT_BAND_UNSTABLE       = 4,   // freq. band unstable during firststartup
  FAULT_BAND_SET_FAILED     = 5,   // band request out of range 0-5
  FAULT_BAND_CHANGE_LIVE    = 6,   // band change attempted during 50V
  FAULT_UART_COMM           = 7,   // UART comm/heartbeat/sync latched
  FAULT_ADC_HARDWARE        = 8,   // ADS1115 / I²C bus fault (rate-limited)
  FAULT_CURRENT_SENSOR      = 9,   // Iamp reads near-zero with meaningful Pout — sensor failed
  FAULT_BIAS_STARTUP        = 10,  // bias current didn't rise within timeout
  FAULT_TUNE_UNSTABLE       = 20,  // freq. unstable during tune (ssb)
  FAULT_INPUT_TOO_HIGH_HW   = 21,  // input too high (over 120W)
  FAULT_ATT_VERIFY          = 22,  // power was too high after att. switch
  FAULT_ATT_NO_REDUCTION    = 23,  // attenuators did not reduce power
  FAULT_RF_LOST_DURING_TUNE = 24,  // !rfPresent() during tune
  FAULT_INPUT_TOO_HIGH_SOFT = 30,  // checks if input power is too high during verify
  FAULT_INPUT_TOO_HIGH_WAIT = 33,  // checks if input power is too high after wait for att. switch
  FAULT_SWR_HIGH            = 40,  // sustained output SWR >3 — soft fault
  FAULT_GAIN_LOW            = 41,  // gain <13dB — soft fault
  FAULT_EFFICIENCY_LOW      = 42,  // efficiency <40% — hard fault
  FAULT_LEAKAGE_CURRENT     = 43,  // >650mA idle with 50V on — hard fault
  FAULT_OVERCURRENT_HW      = 44,  // SR latch tripped by comparator — soft fault
  FAULT_HIGH_REFLECTED      = 45,  // instantaneous high reflected from checkProtectionFast
  FAULT_TEMP_HIGH           = 50,  // heatsink ≥70°C / inner ≥55°C / air ≥50°C — soft fault
  FAULT_TEMP_CRITICAL       = 51,  // heatsink ≥80°C — hard fault (MOSFET case temp)
  FAULT_LOW_VOLTAGE         = 60,  // 18V or 50V rail out of range
  FAULT_HIGH_CURRENT_AVR    = 61,  // overcurrent caught by AVR ADC (SR latch backup)
  FAULT_GATE_DRIFT          = 62,  // checkProtectionSlow tripped — thermal runaway suspect
  FAULT_PA_SUPPLY_LOW       = 63,  // 50V requested, not achieved
  FAULT_PA_SUPPLY_STUCK     = 64,  // 50V not requested, still present
  FAULT_INPUT_SWR_HIGH      = 65,  // input SWR too high
  FAULT_STATE_CORRUPTED     = 98,  // switch hit default branch
  FAULT_EMERGENCY_SHUTDOWN  = 99
} FaultReason_t;

volatile AmpState_t AmpState     = AMP_OFF;
static AmpState_t   PrevAmpState = AMP_OFF;

// Proper entry-action flag — set true once entry actions fire, reset whenever
// the state machine detects we've changed states (see updateAmpState()).
static bool stateEntryDone = false;

// ================= TUNE SUB-STATE =================
static InputPowerTarget_t currentInputTarget = INPUT_PWR_LOW;

// Tune this table against your actual output measurements
InputPowerTarget_t getBandPowerTarget(uint8_t band) {
  switch (band) {
    case 2: return INPUT_PWR_MED;   // 7MHz  — ~650W at 5W, reduce to 3W
    case 3: return INPUT_PWR_MED;   // 14MHz — ~650W at 5W, reduce to 3W
    case 4: return INPUT_PWR_MED;   // 21MHz — ~650W at 5W, reduce to 3W
    default: return INPUT_PWR_HIGH; // 3.5MHz, 28MHz — 5W OK
  }
}
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
